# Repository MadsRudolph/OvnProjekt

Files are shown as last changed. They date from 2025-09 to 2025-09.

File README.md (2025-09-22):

# 🔥 Ovn-Projekt — Pure Analog & Digital Oven Controller (No MCU)






A fully hardware-based oven control system designed and built with **analog + digital electronics** only — **no microcontroller** or pre-programmed ICs.  
All schematics and PCBs were created in **KiCad**. The final project uses a **hierarchical schematic** so all subsystems connect cleanly in one place.

> This was a tough one: we built the oven before learning every theory detail in class. That made it frustrating at times — and incredibly satisfying when everything finally worked.

---

## 🚀 Quick Start (Open the Project)

1. Open **KiCad 7/8** (tested with 8).
2. Open the **main project**:
   - `./OVN/OVN.kicad_pro`
3. Open the **top schematic**:
   - `./OVN/OVN.kicad_sch`  
   This is the top-level design with a **hierarchical sheet** that pulls in all subsystems (analog control, digital timing/state machine, deviation display, oscillator).
4. Optional: open the **PCB**:
   - `./OVN/OVN.kicad_pcb`

> The subfolders contain **intermediate/local variants** and backups. They’re useful for history, but the **final connected design** lives in `OVN/`.

---

## 🎯 Project Goals

- Automatically cycle between **three set temperatures** (e.g., 50 °C → 110 °C → 80 °C → repeat)
- Hold each temperature for a **fixed duration** (e.g., ~80 s)
- Maintain temperature within **±1 °C** of the target
- Provide **safety shutdown** above a critical threshold (e.g., 130 °C)
- Show **real-time temperature deviation** on an LED bar
- Implement everything with **discrete analog + digital logic** (no MCU/firmware)

---

## 🧩 System Overview

The oven control system is composed of **four main subsystems**:

### 1) Digital Oscillator
Generates clock signals for counters/timers and ADC timing.
- RC network + digital logic
- Adjustable frequency outputs
- Example board size around *35 mm × 47 mm*

### 2) Deviation Display (Afvigelsesdisplay)
Real-time visualization of error between current temperature and setpoint.
- **ADC0804** A/D converter
- **Two 74HC238** decoders → **16 LEDs**
- Center LEDs ≈ in-range (green), outer LEDs ≈ negative/positive deviation

### 3) Analog Control Circuit
Compares measured temperature to selected setpoint and drives the heater.
- Sensor: **LM35**
- **Op-amps** for differential amplification & comparators for thresholds
- **CD4066** analog switch selects between three setpoints
- Provides a scaled signal for the deviation display

### 4) Digital State Machine & Timing
Sequences the temperature program and dwell times.
- **74HC163** counters + combinational logic
- Generates `T1/T2/T3` signals for setpoint selection
- Drives indicators (LEDs / 7-segment) and coordinates timing

---
<h2>🧾 Project Poster</h2>
<p align="center">
  <a href="./docs/Ovn_Projekt_Poster.pdf" target="_blank">
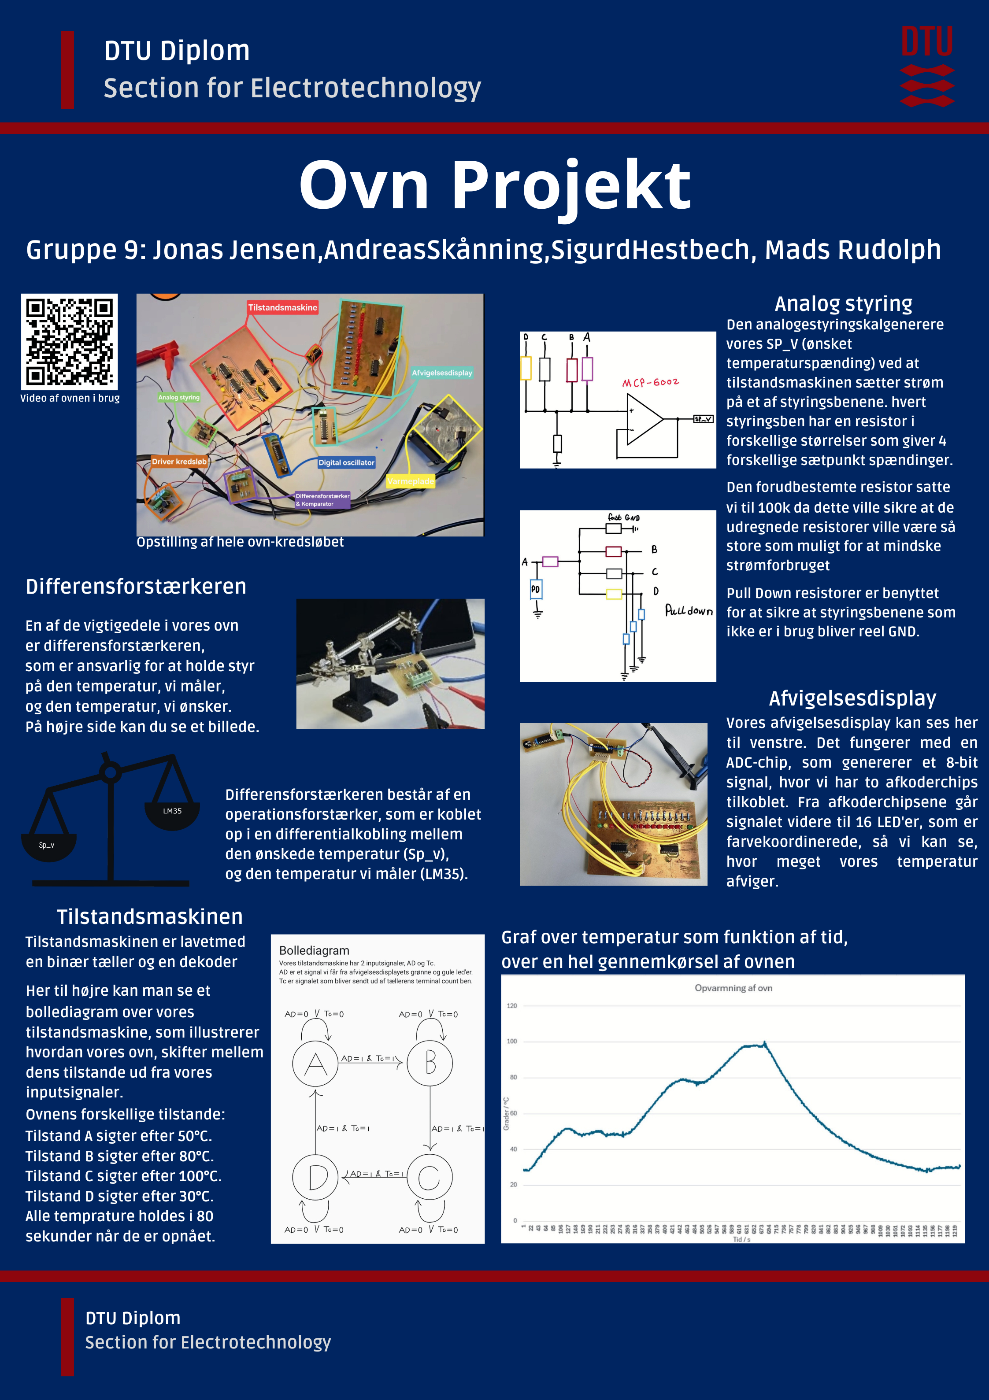
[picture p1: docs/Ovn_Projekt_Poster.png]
Oven Project Poster
    
  </a>
  <br>
  <em>Click to open the full PDF</em>
</p>
---
## 🛠 Tools & Key Components

- **Design:** KiCad (schematic + PCB)
- **Test Gear:** Multimeter, oscilloscope, logic probes/analyzers
- **Key ICs/Parts:** LM35, ADC0804, 74HC238, 74HC163, CD4066, MCP6002, passives, LEDs

---

## ⚡ Workflow

1. **Subsystem Breadboarding** → validate analog thresholds, timing, and LED decoding  
2. **KiCad Schematic & PCB** → create/clean symbols and **custom footprints** as needed  
3. **Integration** → hierarchical sheet in `OVN` ties everything together  
4. **Debug & Iterate** → scope timing edges, adjust thresholds, verify stability and safety

---

## 🌟 Key Learnings

- Designing robust control with **only analog/digital logic** (no firmware safety net)
- Practical timing, noise, and threshold trade-offs in real hardware
- **KiCad** hierarchical design, footprint creation, and multi-board bring-up
- System-level debugging with mixed-signal interactions

---

## 👥 Team

- **Mads Vølkers Rudolph**  
- **Jonas Beck Jensen**
- **Sigurd Hestbech**
- **Andreas Skaaning**

---

## 🚀 Future Improvements

- MCU-based mode for flexible profiles + logging (keeping the analog chain as backup)
- PID/PI control for even tighter regulation
- Small display (OLED/LCD) with progress and temperature graphs

---

## 🏁 Result

The integrated **OVN** project reflects the **final working oven**:  
- Automatic multi-temperature cycling with dwell times  
- Safety cutoff behavior verified  
- Deviation display and timing logic functioning reliably

**No MCU. Just electrons doing the choreography.**

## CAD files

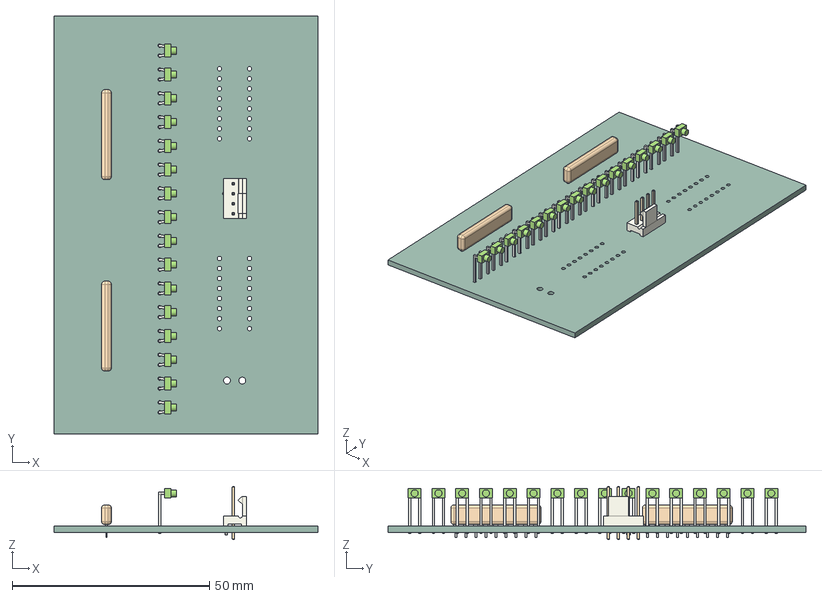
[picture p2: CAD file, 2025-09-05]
Afvigelsesdisplay/afvigelsesdisplay leds/leds/leds.step
67.0 x 106.0 x 13.5 mm
LED_D1.8mm_W1.8mm_H2.4mm_Horizontal_O1.27mm_Z8.2mm x 16
Fan_Pin_Header_Straight_1x04
R_Array_SIP9 x 2
leds_PCB

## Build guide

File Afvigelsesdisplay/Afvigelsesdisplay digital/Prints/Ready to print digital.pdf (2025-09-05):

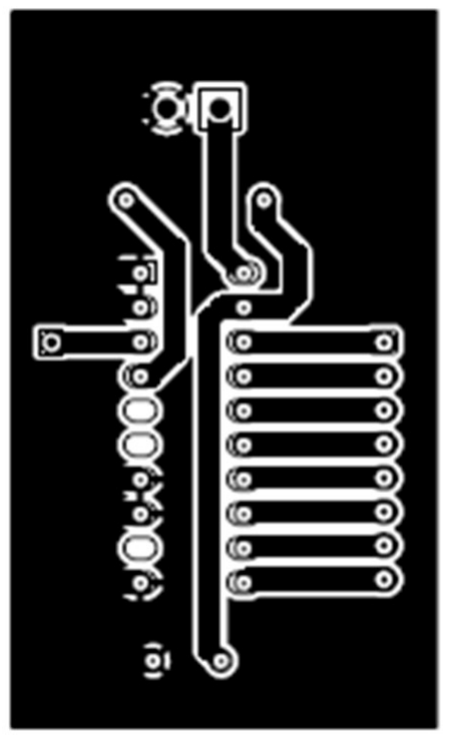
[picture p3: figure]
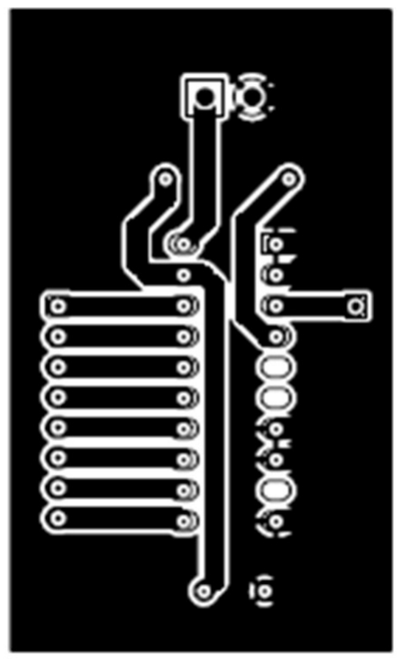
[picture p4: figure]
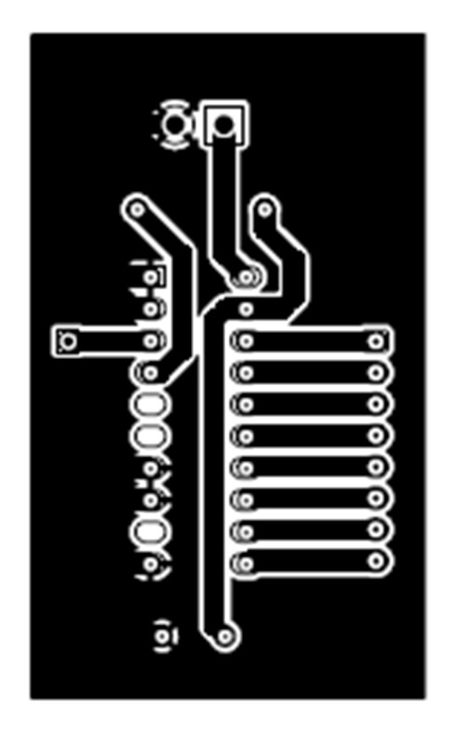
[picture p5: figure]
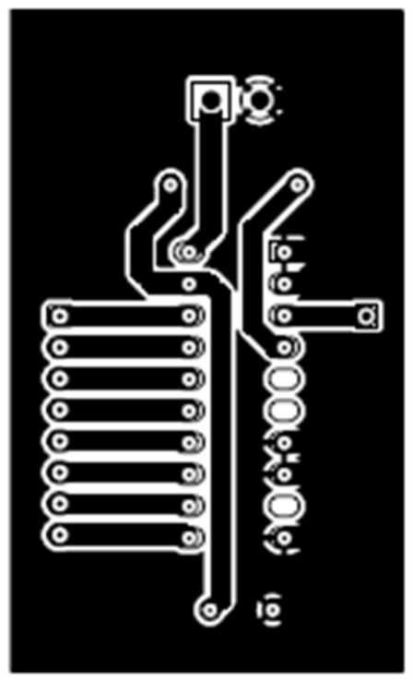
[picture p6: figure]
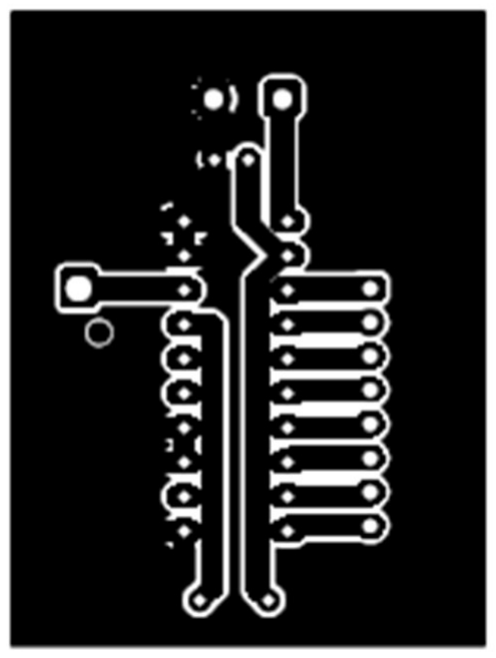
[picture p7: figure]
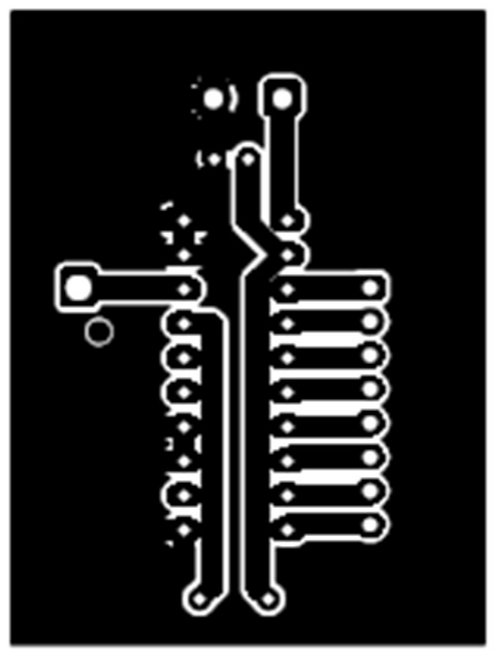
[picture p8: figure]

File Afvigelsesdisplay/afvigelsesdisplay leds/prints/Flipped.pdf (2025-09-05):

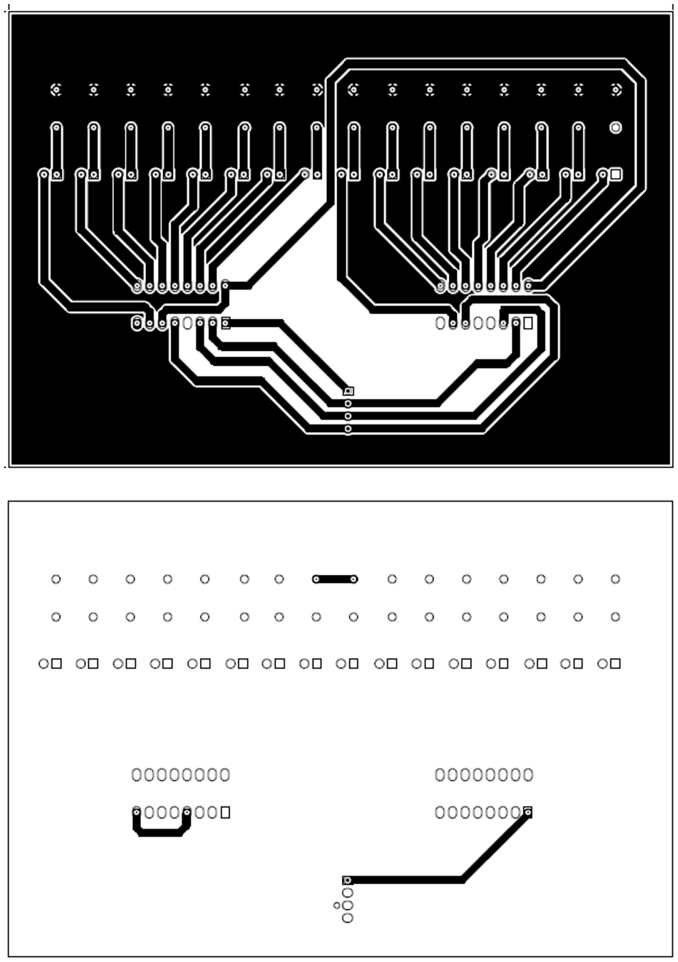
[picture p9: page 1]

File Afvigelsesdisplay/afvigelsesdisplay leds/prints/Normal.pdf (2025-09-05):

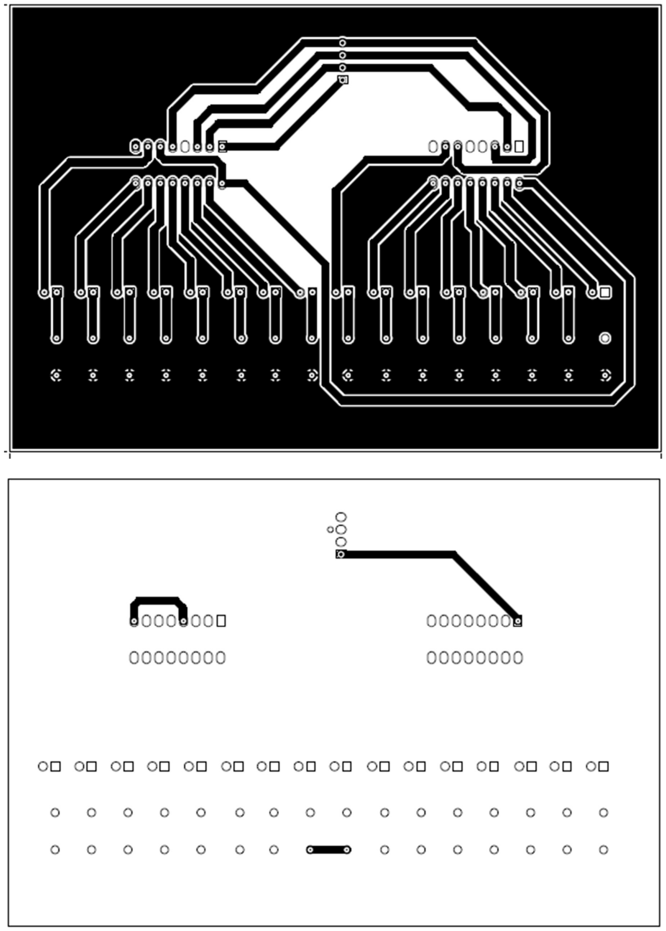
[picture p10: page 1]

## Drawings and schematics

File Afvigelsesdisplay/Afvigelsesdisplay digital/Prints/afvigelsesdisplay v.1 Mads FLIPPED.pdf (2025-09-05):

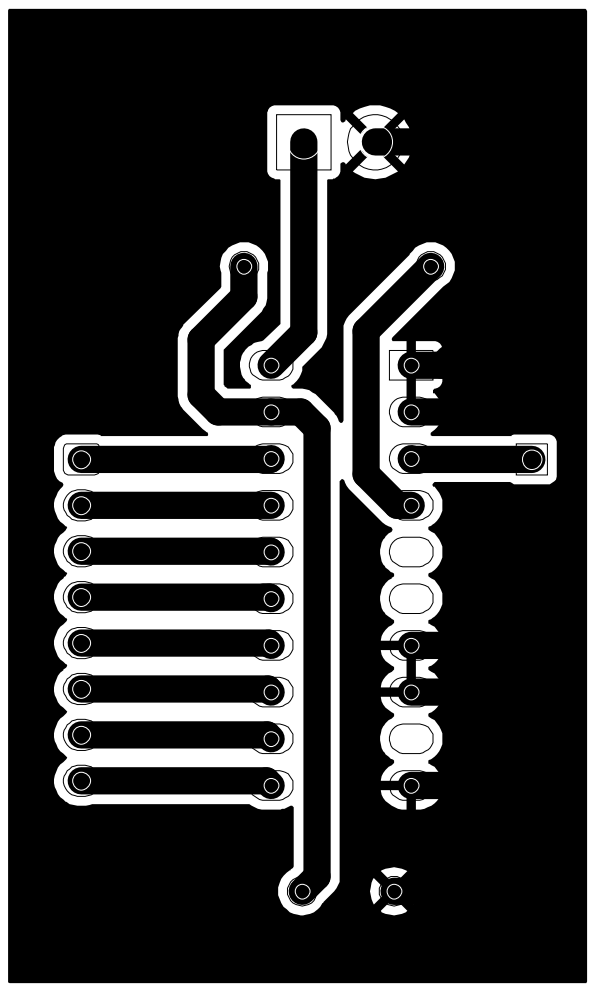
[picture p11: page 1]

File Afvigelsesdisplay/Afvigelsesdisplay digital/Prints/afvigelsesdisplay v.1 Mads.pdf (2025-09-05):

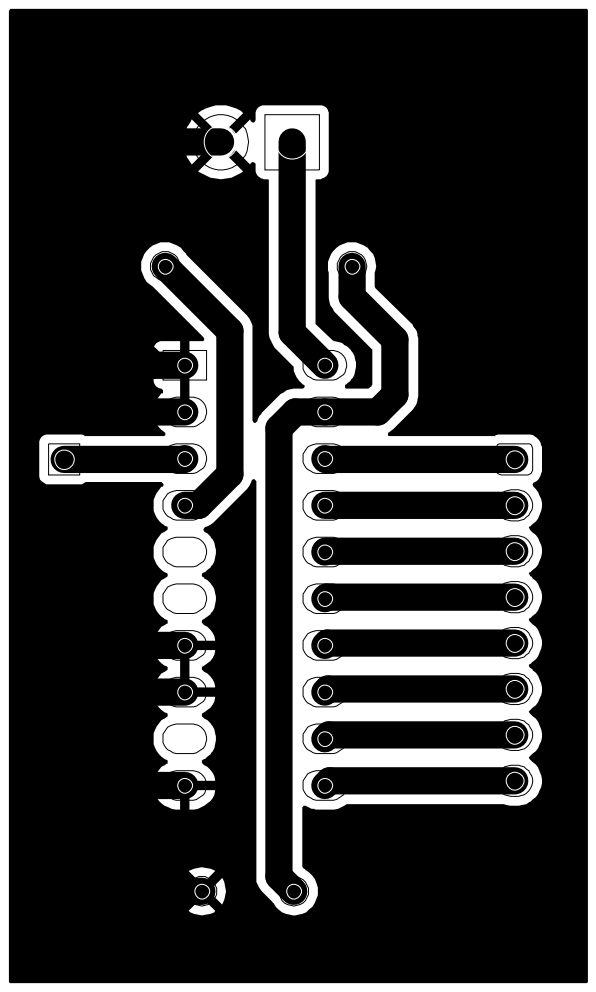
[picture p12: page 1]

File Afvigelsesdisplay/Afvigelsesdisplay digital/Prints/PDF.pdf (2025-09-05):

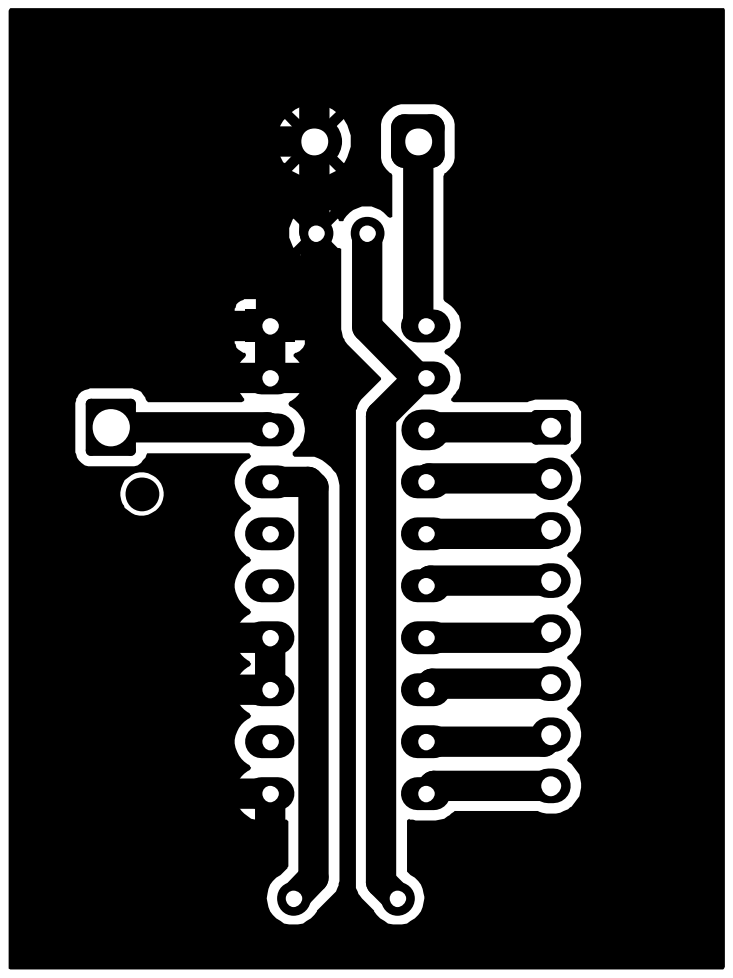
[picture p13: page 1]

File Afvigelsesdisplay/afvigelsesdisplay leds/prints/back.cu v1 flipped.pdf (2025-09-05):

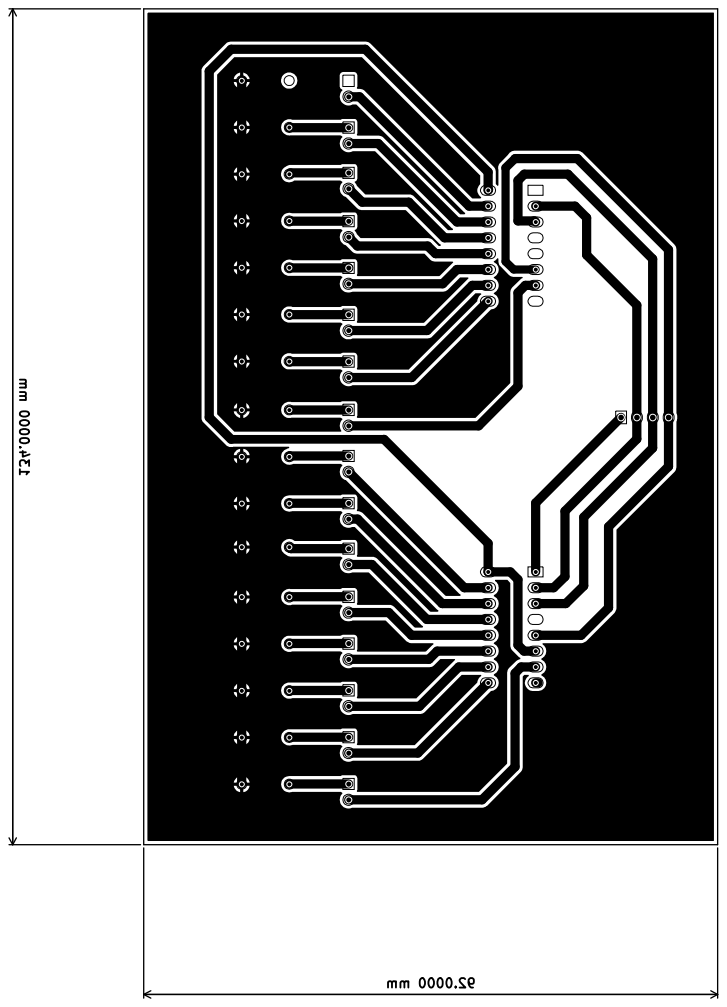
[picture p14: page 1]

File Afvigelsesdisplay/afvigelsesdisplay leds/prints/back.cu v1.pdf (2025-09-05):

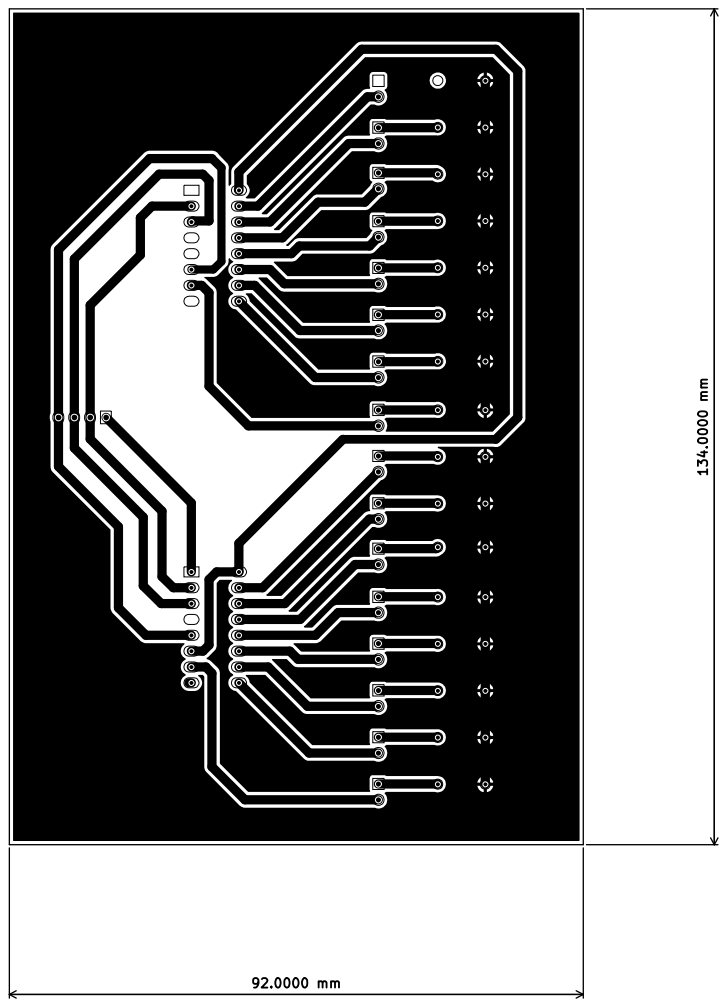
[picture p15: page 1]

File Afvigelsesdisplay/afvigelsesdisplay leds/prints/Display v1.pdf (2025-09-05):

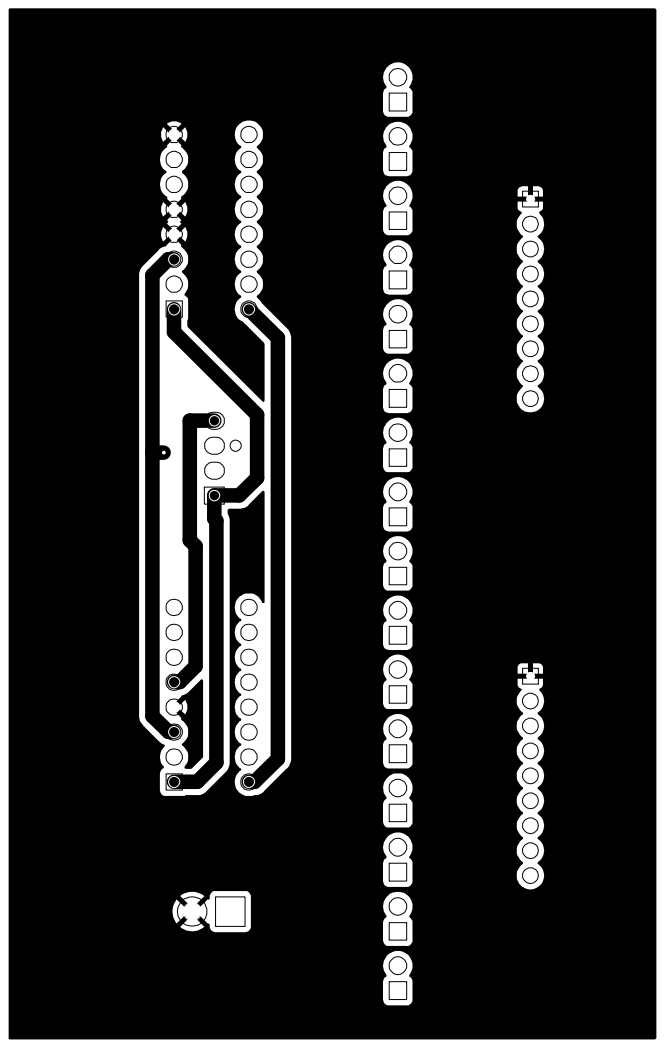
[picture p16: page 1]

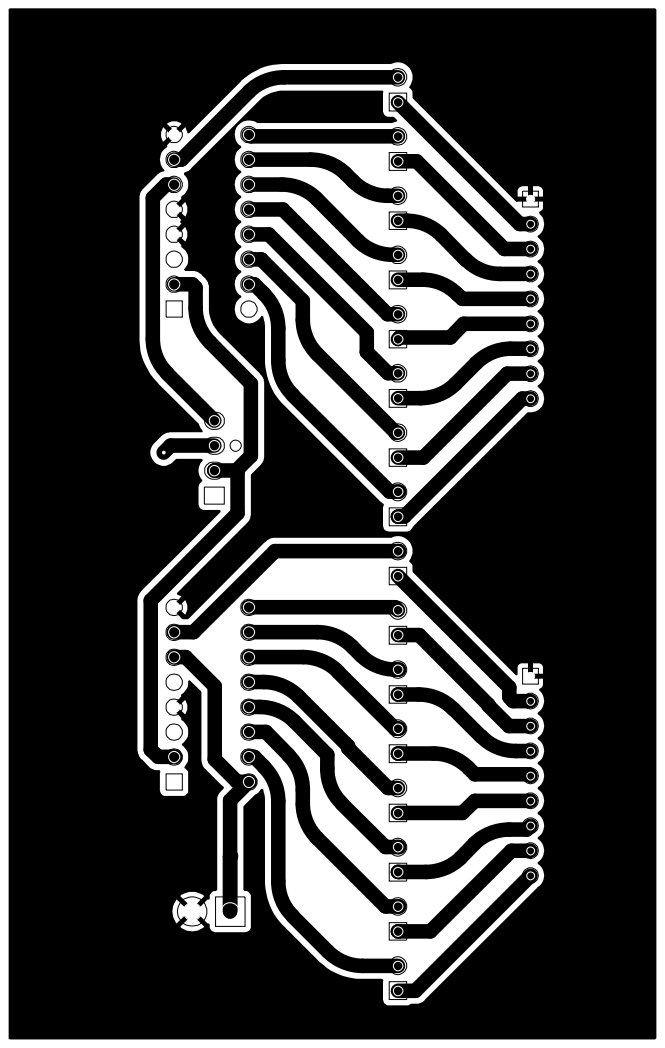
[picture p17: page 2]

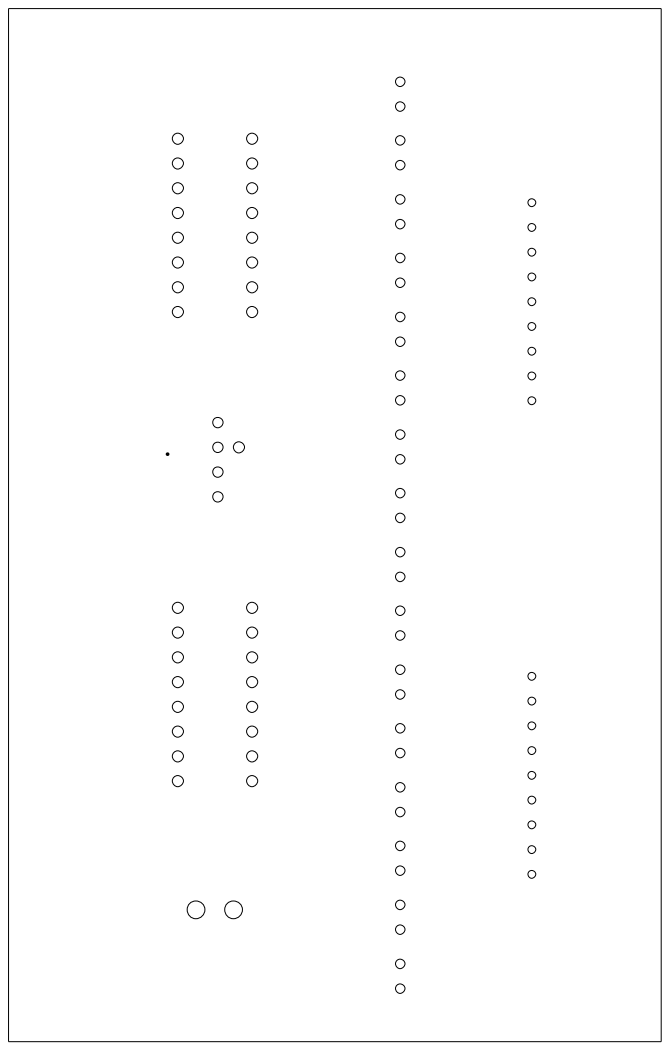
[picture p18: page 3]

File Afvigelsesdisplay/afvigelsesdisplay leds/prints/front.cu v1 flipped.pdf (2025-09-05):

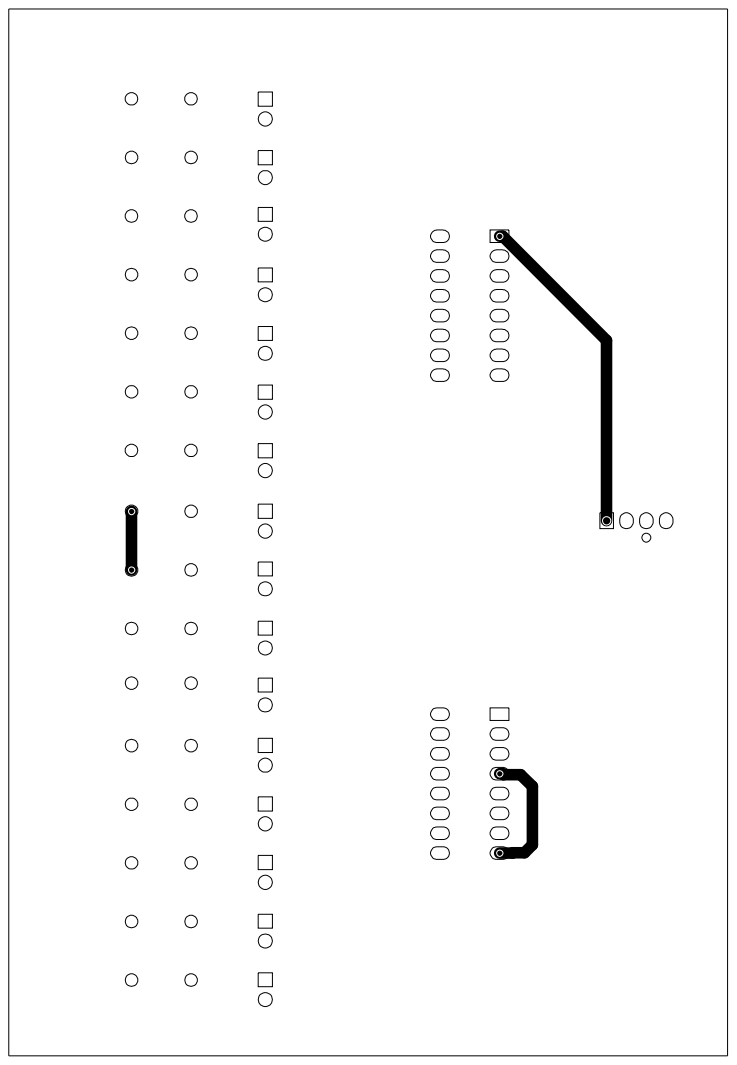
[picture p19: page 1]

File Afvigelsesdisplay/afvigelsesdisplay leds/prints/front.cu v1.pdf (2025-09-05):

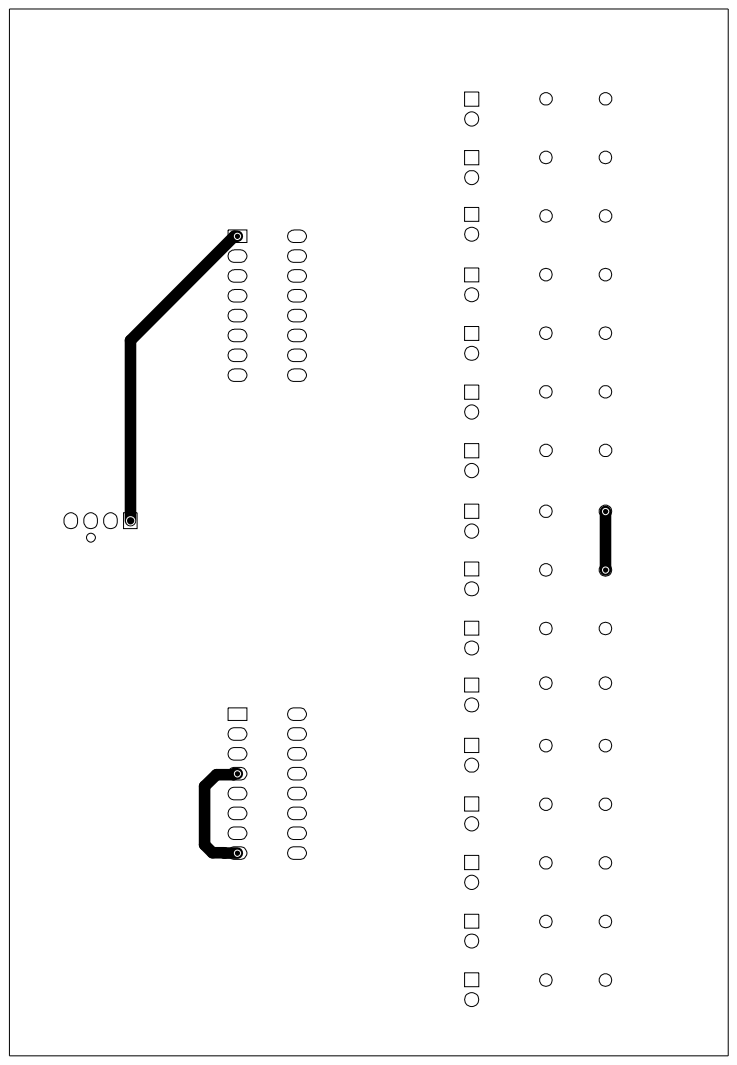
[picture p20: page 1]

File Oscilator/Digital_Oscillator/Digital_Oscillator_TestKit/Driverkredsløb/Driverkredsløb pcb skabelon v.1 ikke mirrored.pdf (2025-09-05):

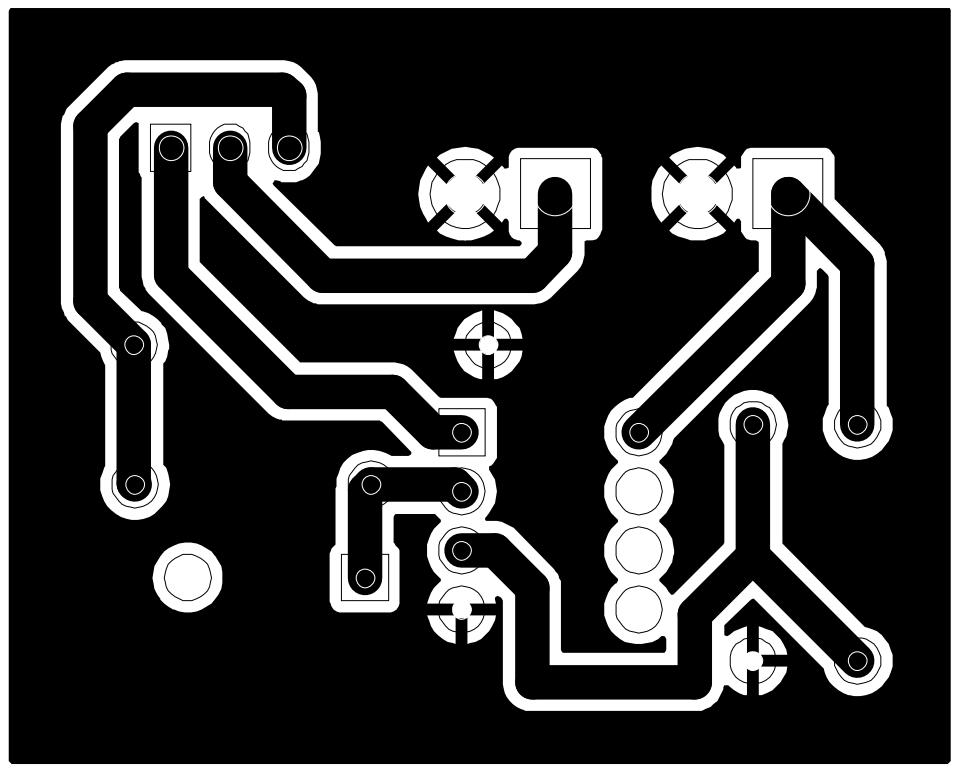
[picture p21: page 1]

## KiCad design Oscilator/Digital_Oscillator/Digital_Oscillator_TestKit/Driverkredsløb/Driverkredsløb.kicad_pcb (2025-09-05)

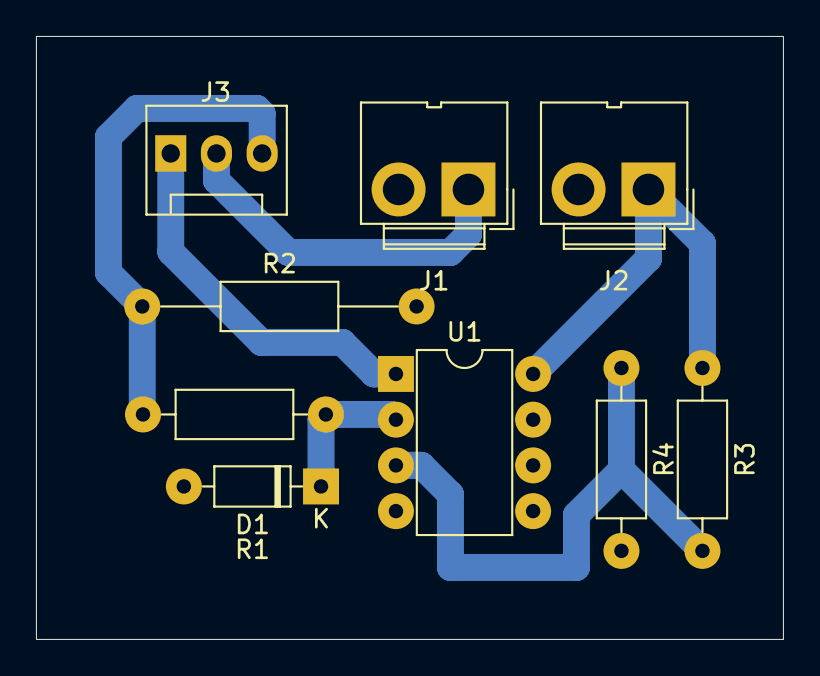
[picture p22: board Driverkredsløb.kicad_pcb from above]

Board: 2 copper layers, 41.5 x 33.5 mm, 9 parts (0 on the bottom side), 7 nets.

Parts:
D1: 1N4148; D_DO-35_SOD27_P7.62mm_Horizontal
J1, J2: Conn_01x02_Socket; JWT_A3963_1x02_P3.96mm_Vertical
J3: Conn_01x03_Socket; FanPinHeader_1x03_P2.54mm_Vertical
R1: 20k; R_Axial_DIN0207_L6.3mm_D2.5mm_P10.16mm_Horizontal
R2: 0.1; R_Axial_DIN0207_L6.3mm_D2.5mm_P15.24mm_Horizontal
R3: 15k; R_Axial_DIN0207_L6.3mm_D2.5mm_P10.16mm_Horizontal
R4: 300; R_Axial_DIN0207_L6.3mm_D2.5mm_P10.16mm_Horizontal
U1: MCP6002-xMC; DIP-8_W7.62mm

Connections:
GND: J1.2, J2.2, R2.2, R4.2, U1.4 (V-)
unnamed: D1.1 (K), R1.1, U1.2 (-)
unnamed: J1.1, J3.2
unnamed: J2.1, R3.1, U1.8 (V+)
unnamed: J3.1, U1.1
unnamed: J3.3, R1.2, R2.1
unnamed: R3.2, R4.1, U1.3 (+)

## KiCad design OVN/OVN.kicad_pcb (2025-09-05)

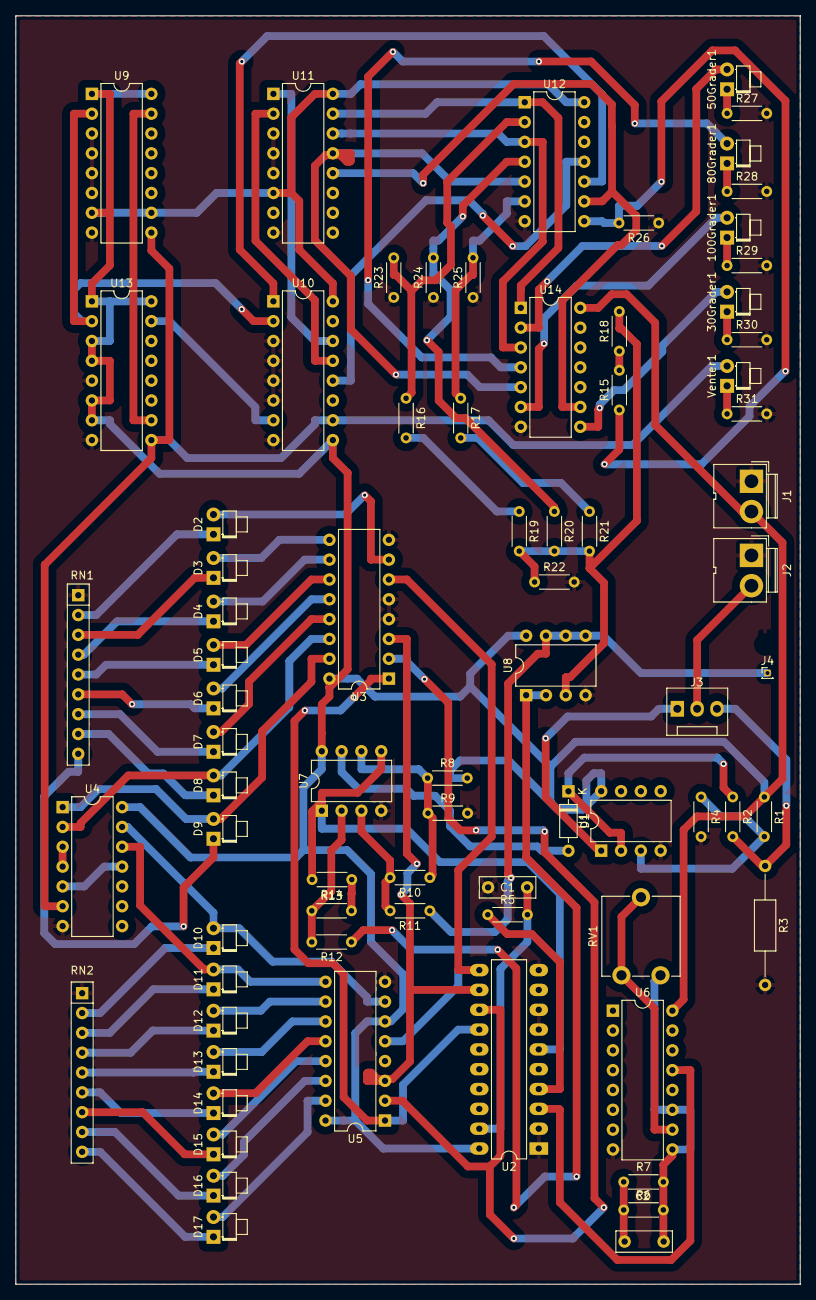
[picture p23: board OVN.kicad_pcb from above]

Board: 2 copper layers, 100.5 x 162.5 mm, 76 parts (0 on the bottom side), 87 nets.

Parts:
30Grader1, 50Grader1, 80Grader1, 100Grader1: LED; LED_D1.8mm_W1.8mm_H2.4mm_Horizontal_O1.27mm_Z8.2mm
C1: 150nF; C_Disc_D7.0mm_W2.5mm_P5.00mm
C2: 100 nF; C_Disc_D7.0mm_W2.5mm_P5.00mm
D1: 1N4148; D_DO-35_SOD27_P7.62mm_Horizontal
D2, D4, D5, D6, D7, D12, D13, D14, D15, D16, D17: R; LED_D1.8mm_W1.8mm_H2.4mm_Horizontal_O1.27mm_Z8.2mm
D3: LED; LED_D1.8mm_W1.8mm_H2.4mm_Horizontal_O1.27mm_Z8.2mm
D8, D11: GU; LED_D1.8mm_W1.8mm_H2.4mm_Horizontal_O1.27mm_Z8.2mm
D9, D10: GR; LED_D1.8mm_W1.8mm_H2.4mm_Horizontal_O1.27mm_Z8.2mm
J1, J2: Conn_01x02_Pin; JWT_A3963_1x02_P3.96mm_Vertical
J3: Conn_01x03_Socket; FanPinHeader_1x03_P2.54mm_Vertical
J4: LM35; PinHeader_1x01_P1.00mm_Vertical
R1: 15k; R_Axial_DIN0204_L3.6mm_D1.6mm_P5.08mm_Horizontal
R2: 20k; R_Axial_DIN0204_L3.6mm_D1.6mm_P5.08mm_Horizontal
R3: 0.1; R_Axial_DIN0207_L6.3mm_D2.5mm_P15.24mm_Horizontal
R4: 300; R_Axial_DIN0204_L3.6mm_D1.6mm_P5.08mm_Horizontal
R5, R22: 100K; R_Axial_DIN0204_L3.6mm_D1.6mm_P5.08mm_Horizontal
R6: 4.3k; R_Axial_DIN0204_L3.6mm_D1.6mm_P5.08mm_Horizontal
R7: 123K6; R_Axial_DIN0204_L3.6mm_D1.6mm_P5.08mm_Horizontal
R8, R9, R14: 11.5K; R_Axial_DIN0204_L3.6mm_D1.6mm_P5.08mm_Horizontal
R10, R13: 301K; R_Axial_DIN0204_L3.6mm_D1.6mm_P5.08mm_Horizontal
R11, R12: 10K; R_Axial_DIN0204_L3.6mm_D1.6mm_P5.08mm_Horizontal
R15: 787K; R_Axial_DIN0204_L3.6mm_D1.6mm_P5.08mm_Horizontal
R16: 5.6K; R_Axial_DIN0204_L3.6mm_D1.6mm_P5.08mm_Horizontal
R17: 237K; R_Axial_DIN0204_L3.6mm_D1.6mm_P5.08mm_Horizontal
R18: 15K; R_Axial_DIN0204_L3.6mm_D1.6mm_P5.08mm_Horizontal
R19: 475K; R_Axial_DIN0204_L3.6mm_D1.6mm_P5.08mm_Horizontal
R20: 300K; R_Axial_DIN0204_L3.6mm_D1.6mm_P5.08mm_Horizontal
R21: 2.6K; R_Axial_DIN0204_L3.6mm_D1.6mm_P5.08mm_Horizontal
R23, R24, R25, R26, R27, R28, R29, R30, R31: R; R_Axial_DIN0204_L3.6mm_D1.6mm_P5.08mm_Horizontal
RN1, RN2: R_Network08; R_Array_SIP9
RV1: R_Potentiometer_Small; Potentiometer_ACP_CA9-V10_Vertical
U1, U7, U8: MCP6002-xMC; DIP-8_W7.62mm
U2: ADC0804LCN; DIP-20_W7.62mm_LongPads
U3, U5: 74HC238N; DIP-16_W7.62mm
U4: SN74HC86; DIP-14_W7.62mm
U6: 74HC4060; DIP-16_W7.62mm
U9, U10, U13: SN74HC163N; DIP-16_W7.62mm
U11: 74HC138N; DIP-16_W7.62mm
U12, U14: SN74HC04N; DIP-14_W7.62mm
Venter1: LED; LED_D1.8mm_W1.8mm_H2.4mm_Horizontal_O1.27mm_Z8.2mm

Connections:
10V-30V: J2.2, J3.2
+5V: J1.2, R1.1, R8.2, U1.8 (V+), U2.20 (VCC), U3.16 (VCC), U4.14 (VCC), U5.6 (E3), U5.16 (VCC), U6.16 (VDD), U7.8 (V+), U8.8 (V+), U9.1 (~MR), U9.7 (CEP), U9.10 (CET), U9.16 (VCC), U10.9 (~LOAD), U10.16 (VCC), U11.6 (E3), U11.16 (VCC), U12.14 (VCC), U13.1 (~MR), U13.3 (D0), U13.4 (D1), U13.6 (D3), U13.7 (CEP), U13.16 (VCC), U14.14 (VCC)
/ADC Convertor/DB4: U2.14 (DB4), U3.1 (A0), U5.1 (A0)
/ADC Convertor/DB5: U2.13 (DB5), U3.2 (A1), U5.2 (A1)
/ADC Convertor/DB6: U2.12 (DB6), U3.3 (A2), U5.3 (A2)
/ADC Convertor/DB7: U2.11 (DB7), U3.6 (E3), U5.5 (~E2)
/ADC Convertor/WR_in: U2.3 (~WR), U6.13 (Q9), U9.2 (CLK), U10.2 (CLK), U13.2 (CLK)
/Afvigelsesdisplay/Steady state: U4.6 (3Y), U9.9 (~LOAD), U10.10 (CET), U13.9 (~LOAD), Venter1.2 (A)
/Analog styring Differensforstærker/V-Ovn: D1.2 (A), U7.7
/Analog styring spændingsdeler/30°C: R15.1, R26.2, U12.8 (4Y)
/Analog styring spændingsdeler/50°C: R16.1, R23.2, U12.2 (1Y)
/Analog styring spændingsdeler/80°C: R20.1, R24.2, U12.4 (2Y)
/Analog styring spændingsdeler/100°C: R17.1, R25.2, U12.6 (3Y)
Afv_displ_adc: R14.2, U2.6 (VIN(+)), U7.1, U7.5 (+)
GND: C1.1, J1.1, J2.1, R3.2, R4.2, R9.2, R22.2, R23.1, R24.1, R25.1, R26.1, R27.2, R28.2, R29.2, R30.2, R31.2, RN1.1 (common), RN2.1 (common), U1.4 (V-), U2.1 (~CS), U2.2 (~RD), U2.7 (VIN(-)), U2.8 (AGND), U2.10 (DGND), U3.4 (~E1), U3.5 (~E2), U3.8 (GND), U4.7 (GND), U5.4 (~E1), U5.8 (GND), U6.8 (VSS), U6.12 (CLR), U7.4 (V-), U8.4 (V-), U9.3 (D0), U9.4 (D1), U9.5 (D2), U9.6 (D3), U9.8 (GND), U10.3 (D0), U10.4 (D1), U10.5 (D2), U10.6 (D3), U10.8 (GND), U11.3 (A2), U11.4 (~E1), U11.5 (~E2), U11.8 (GND), U12.7 (GND), U13.5 (D2), U13.8 (GND), U14.7 (GND)
LM35_out: J4.1, R11.1, U8.5 (+), U8.6 (-), U8.7
unnamed: 30Grader1.2 (A), U14.8 (4Y)
unnamed: 30Grader1.1 (K), R30.1
unnamed: 50Grader1.2 (A), U14.2 (1Y)
unnamed: 50Grader1.1 (K), R27.1
unnamed: 80Grader1.2 (A), U14.4 (2Y)
unnamed: 80Grader1.1 (K), R28.1
unnamed: 100Grader1.2 (A), U14.6 (3Y)
unnamed: 100Grader1.1 (K), R29.1
unnamed: C2.1, R6.1, R7.1
unnamed: D1.1 (K), R2.1, U1.2 (-)
unnamed: D2.2 (A), U3.7 (Y7)
unnamed: D2.1 (K), RN1.2 (R1)
unnamed: D3.2 (A), U3.9 (Y6)
unnamed: D3.1 (K), RN1.3 (R2)
unnamed: D4.2 (A), U3.10 (Y5)
unnamed: D4.1 (K), RN1.4 (R3)
unnamed: D5.2 (A), U3.11 (Y4)
unnamed: D5.1 (K), RN1.5 (R4)
unnamed: D6.2 (A), U3.12 (Y3)
unnamed: D6.1 (K), RN1.6 (R5)
unnamed: D7.2 (A), U3.13 (Y2)
unnamed: D7.1 (K), RN1.7 (R6)
unnamed: D8.2 (A), U3.14 (Y1), U4.2 (1Y)
unnamed: D8.1 (K), RN1.8 (R7)
unnamed: D9.2 (A), U3.15 (Y0), U4.1 (1A)
unnamed: D9.1 (K), RN1.9 (R8)
unnamed: D10.2 (A), U4.13 (6A), U5.7 (Y7)
unnamed: D10.1 (K), RN2.2 (R1)
unnamed: D11.2 (A), U4.12 (6Y), U5.9 (Y6)
unnamed: D11.1 (K), RN2.3 (R2)
unnamed: D12.2 (A), U5.10 (Y5)
unnamed: D12.1 (K), RN2.4 (R3)
unnamed: D13.2 (A), U5.11 (Y4)
unnamed: D13.1 (K), RN2.5 (R4)
unnamed: D14.2 (A), U5.12 (Y3)
unnamed: D14.1 (K), RN2.6 (R5)
unnamed: D15.2 (A), U5.13 (Y2)
unnamed: D15.1 (K), RN2.7 (R6)
unnamed: D16.2 (A), U5.14 (Y1)
unnamed: D16.1 (K), RN2.8 (R7)
unnamed: D17.2 (A), U5.15 (Y0)
unnamed: D17.1 (K), RN2.9 (R8)
unnamed: J3.1, U1.1
unnamed: J3.3, R2.2, R3.1
unnamed: R13.2, R14.1
unnamed: R15.2, R18.1
unnamed: R16.2, R19.1
unnamed: R17.2, R21.1
unnamed: R1.2, R4.1, U1.3 (+)
unnamed: R5.1, U2.4 (CLK_IN)
unnamed: C1.2, R5.2, U2.19 (CLK_R)
unnamed: U4.3 (2A), U4.4 (2Y)
unnamed: U4.5 (3A), U4.11 (5A)
unnamed: C2.2, R6.2, R7.2, RV1.1, U6.9 (~Φ0), U6.11 (~Φ1)
unnamed: RV1.2, RV1.3, U6.10 (Φ0)
unnamed: R10.2, R11.2, U7.3 (+)
unnamed: R12.2, R13.1, U7.2 (-)
unnamed: R8.1, R9.1, R10.1, U7.6 (-)
unnamed: R18.2, R19.2, R20.2, R21.2, R22.1, U8.3 (+)
unnamed: U10.7 (CEP), U13.15 (TC)
unnamed: U10.14 (Q0), U11.1 (A0)
unnamed: U10.13 (Q1), U11.2 (A1)
unnamed: U10.12 (Q2), U12.11 (5A)
unnamed: U10.1 (~MR), U12.10 (5Y)
unnamed: U11.15 (Y0), U12.1 (1A), U14.1 (1A)
unnamed: U11.14 (Y1), U12.3 (2A), U14.3 (2A)
unnamed: U11.13 (Y2), U12.5 (3A), U14.5 (3A)
unnamed: U11.12 (Y3), U12.9 (4A), U14.9 (4A)
unnamed: U9.15 (TC), U13.10 (CET)
unnamed: R31.1, Venter1.1 (K)
Sp_v: R12.1, U8.1, U8.2 (-)

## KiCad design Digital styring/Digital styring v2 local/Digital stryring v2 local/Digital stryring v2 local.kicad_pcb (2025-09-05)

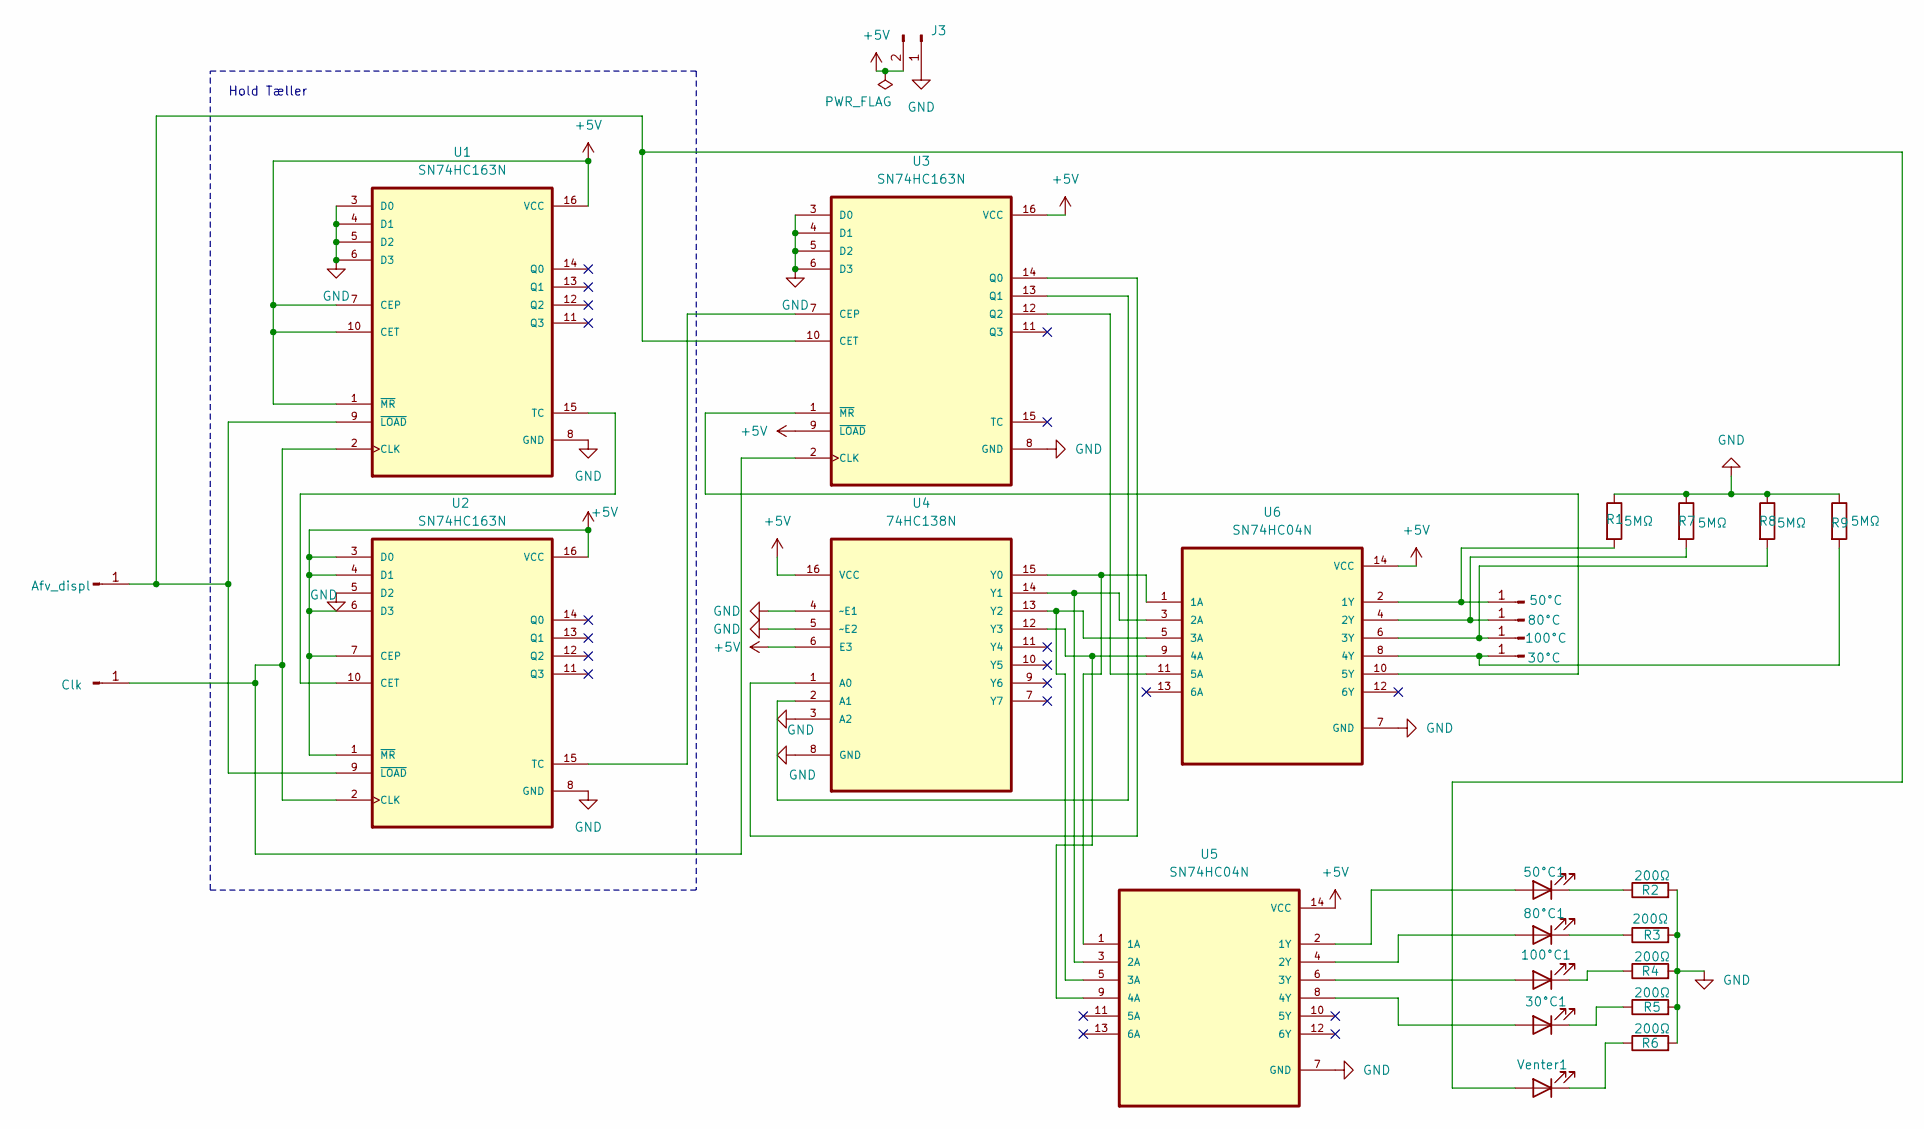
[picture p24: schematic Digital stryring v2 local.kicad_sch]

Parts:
30°C1, 50°C1, 80°C1, 100°C1: LED; LED_D1.8mm_W1.8mm_H2.4mm_Horizontal_O1.27mm_Z8.2mm
J1: Afv_displ; PinHeader_1x01_P1.00mm_Vertical
J2: Clk; PinHeader_1x01_P1.00mm_Vertical
J3: Conn_01x02_Pin; JWT_A3963_1x02_P3.96mm_Vertical
J4: 50°C; PinHeader_1x01_P1.00mm_Vertical
J5: 80°C; PinHeader_1x01_P1.00mm_Vertical
J6: 100°C; PinHeader_1x01_P1.00mm_Vertical
J7: 30°C; PinHeader_1x01_P1.00mm_Vertical
R1, R7, R8, R9: 5MΩ; R_Axial_DIN0204_L3.6mm_D1.6mm_P7.62mm_Horizontal
R2, R3, R4, R5, R6: 200Ω; R_Axial_DIN0204_L3.6mm_D1.6mm_P5.08mm_Horizontal
U1, U2, U3: SN74HC163N; DIP-16_W7.62mm
U4: 74HC138N; DIP-16_W7.62mm; MPN 74HC238N
U5, U6: SN74HC04N; DIP-14_W7.62mm
Venter1: LED; LED_D1.8mm_W1.8mm_H2.4mm_Horizontal_O1.27mm_Z8.2mm

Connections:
+5V: J3.2, U1.1 (~MR), U1.7 (CEP), U1.10 (CET), U1.16 (VCC), U2.1 (~MR), U2.3 (D0), U2.4 (D1), U2.6 (D3), U2.7 (CEP), U2.16 (VCC), U3.9 (~LOAD), U3.16 (VCC), U4.6 (E3), U4.16 (VCC), U5.14 (VCC), U6.14 (VCC)
GND: J3.1, R1.1, R2.2, R3.2, R4.2, R5.2, R6.2, R7.1, R8.1, R9.1, U1.3 (D0), U1.4 (D1), U1.5 (D2), U1.6 (D3), U1.8 (GND), U2.5 (D2), U2.8 (GND), U3.3 (D0), U3.4 (D1), U3.5 (D2), U3.6 (D3), U3.8 (GND), U4.3 (A2), U4.4 (~E1), U4.5 (~E2), U4.8 (GND), U5.7 (GND), U6.7 (GND)
unnamed: 30°C1.2 (A), U5.8 (4Y)
unnamed: 30°C1.1 (K), R5.1
unnamed: 50°C1.2 (A), U5.2 (1Y)
unnamed: 50°C1.1 (K), R2.1
unnamed: 80°C1.2 (A), U5.4 (2Y)
unnamed: 80°C1.1 (K), R3.1
unnamed: 100°C1.2 (A), U5.6 (3Y)
unnamed: 100°C1.1 (K), R4.1
unnamed: J1.1, U1.9 (~LOAD), U2.9 (~LOAD), U3.10 (CET), Venter1.2 (A)
unnamed: J2.1, U1.2 (CLK), U2.2 (CLK), U3.2 (CLK)
unnamed: J4.1, R1.2, U6.2 (1Y)
unnamed: J5.1, R7.2, U6.4 (2Y)
unnamed: J6.1, R8.2, U6.6 (3Y)
unnamed: J7.1, R9.2, U6.8 (4Y)
unnamed: U1.15 (TC), U2.10 (CET)
unnamed: U2.15 (TC), U3.7 (CEP)
unnamed: U3.14 (Q0), U4.1 (A0)
unnamed: U3.13 (Q1), U4.2 (A1)
unnamed: U3.12 (Q2), U6.11 (5A)
unnamed: U3.1 (~MR), U6.10 (5Y)
unnamed: U4.15 (Y0), U5.1 (1A), U6.1 (1A)
unnamed: U4.14 (Y1), U5.3 (2A), U6.3 (2A)
unnamed: U4.13 (Y2), U5.5 (3A), U6.5 (3A)
unnamed: U4.12 (Y3), U5.9 (4A), U6.9 (4A)
unnamed: R6.1, Venter1.1 (K)

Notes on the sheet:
Hold Tæller

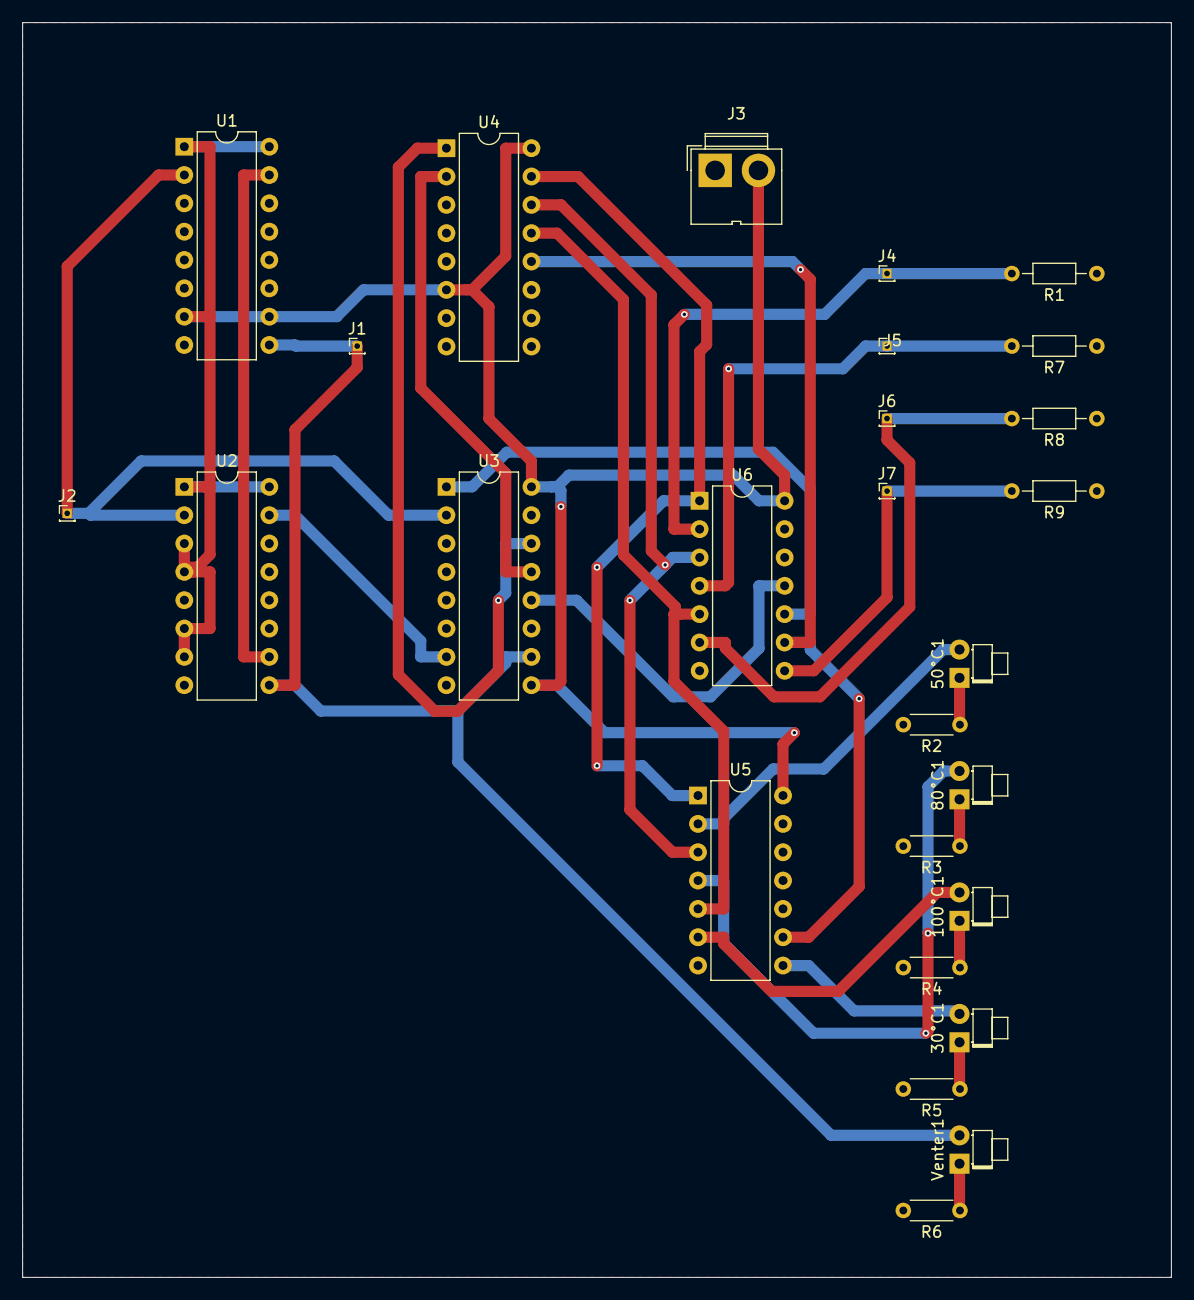
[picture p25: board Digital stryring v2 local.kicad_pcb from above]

Board: 2 copper layers, 103.0 x 112.5 mm, 27 parts (0 on the bottom side), 27 nets.

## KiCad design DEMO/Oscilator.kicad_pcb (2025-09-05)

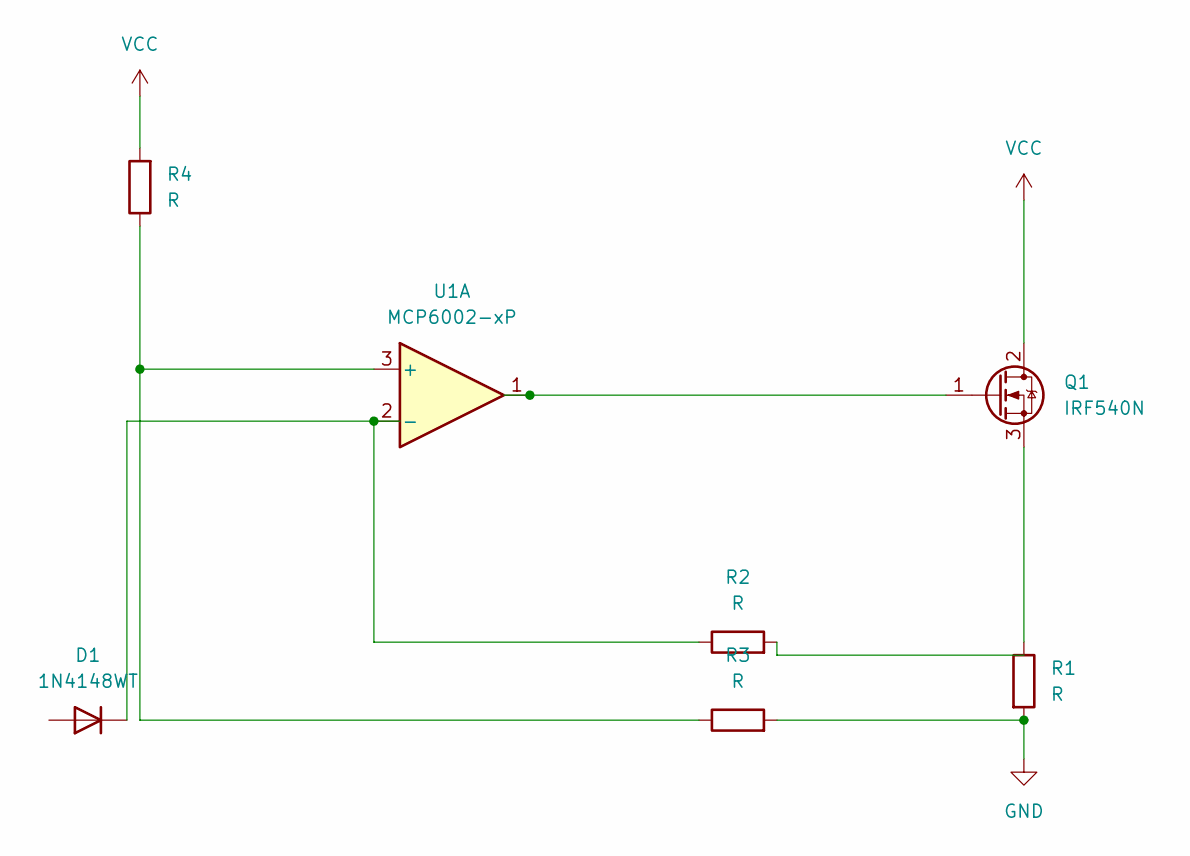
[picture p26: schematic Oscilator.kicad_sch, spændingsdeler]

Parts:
D1: 1N4148WT; D_SOD-523
Q1: IRF540N; TO-220-3_Vertical
R1, R2, R3, R4: R; R_Axial_DIN0207_L6.3mm_D2.5mm_P7.62mm_Horizontal
U1: MCP6002-xP; CERDIP-8_W7.62mm_SideBrazed_Socket

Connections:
GND: R1.2, R3.2
unnamed: D1.1 (K), R2.1, U1.2 (-)
unnamed: Q1.1 (G), U1.1
unnamed: Q1.3 (S), R1.1
unnamed: R3.1, R4.1, U1.3 (+)
VCC: Q1.2 (D), R4.2

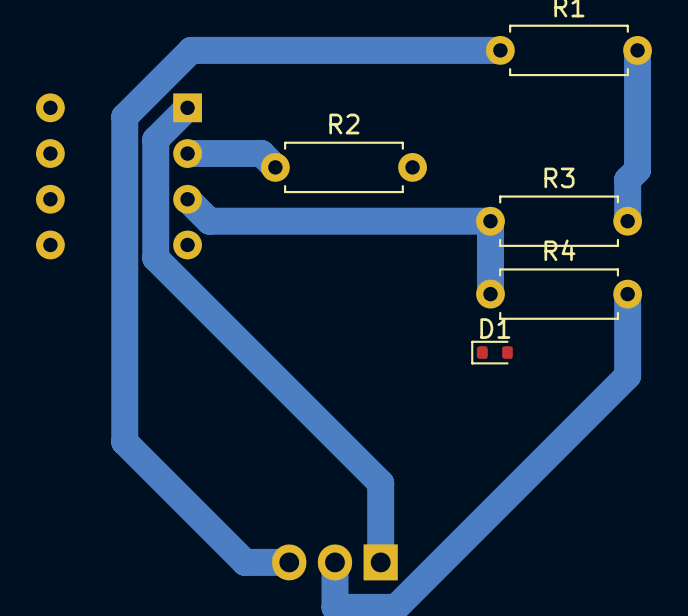
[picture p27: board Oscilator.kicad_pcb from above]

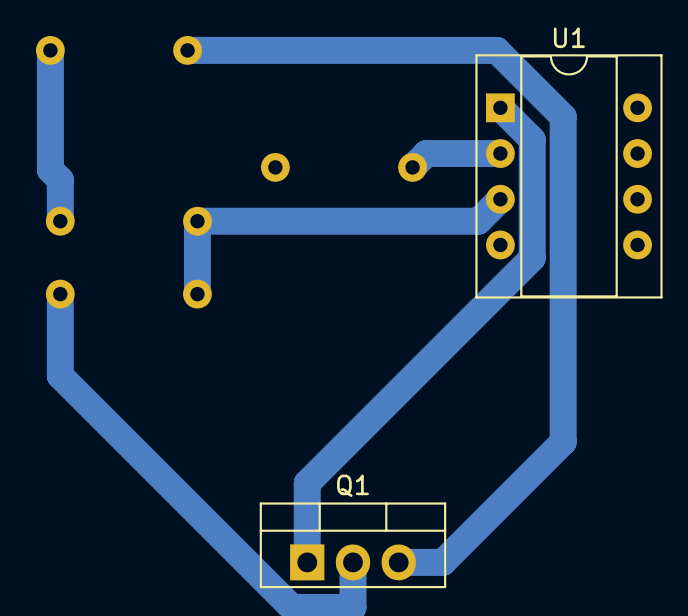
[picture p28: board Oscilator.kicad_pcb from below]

Board: 2 copper layers, 7 parts (2 on the bottom side), 6 nets.

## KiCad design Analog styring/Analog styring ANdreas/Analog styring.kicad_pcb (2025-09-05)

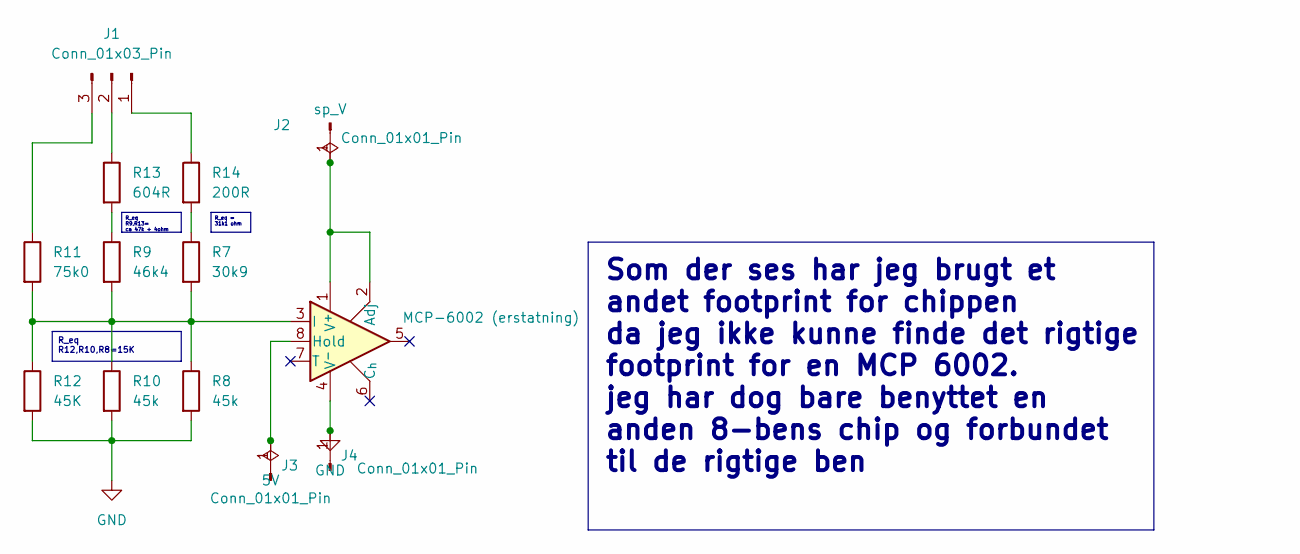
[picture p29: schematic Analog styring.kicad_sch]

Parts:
J1: Conn_01x03_Pin; FanPinHeader_1x03_P2.54mm_Vertical
J2, J3, J4: Conn_01x01_Pin; PinHeader_1x01_P1.00mm_Vertical
R7: 30k9; R_Axial_DIN0204_L3.6mm_D1.6mm_P2.54mm_Vertical
R8, R10: 45k; R_Axial_DIN0204_L3.6mm_D1.6mm_P2.54mm_Vertical
R9: 46k4; R_Axial_DIN0204_L3.6mm_D1.6mm_P2.54mm_Vertical
R11: 75k0; R_Axial_DIN0204_L3.6mm_D1.6mm_P2.54mm_Vertical
R12: 45K; R_Axial_DIN0204_L3.6mm_D1.6mm_P2.54mm_Vertical
R13: 604R; R_Axial_DIN0204_L3.6mm_D1.6mm_P2.54mm_Vertical
R14: 200R; R_Axial_DIN0204_L3.6mm_D1.6mm_P2.54mm_Vertical
U1: MCP-6002 (erstatning); DIP-8_W7.62mm

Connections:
GND: J4.1, R8.2, R10.2, R12.2, U1.4 (V^{-})
unnamed: J1.1, R14.1
unnamed: J1.2, R13.1
unnamed: J1.3, R11.1
unnamed: J2.1, U1.1 (V^{+}), U1.2 (Adj)
unnamed: J3.1, U1.8 (Hold)
unnamed: R9.1, R13.2
unnamed: R7.1, R14.2
unnamed: R7.2, R8.1, R9.2, R10.1, R11.2, R12.1, U1.3 (I)

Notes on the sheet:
Som der ses har jeg brugt et andet footprint for chippen da jeg ikke kunne finde det rigtige footprint for en MCP 6002. jeg har dog bare benyttet en anden 8-bens chip og forbundet til de rigtige ben
R_eq R9,R13= ca 47k + 4ohm
R_eq R12,R10,R8=15K
R_eq = 31k1 ohm

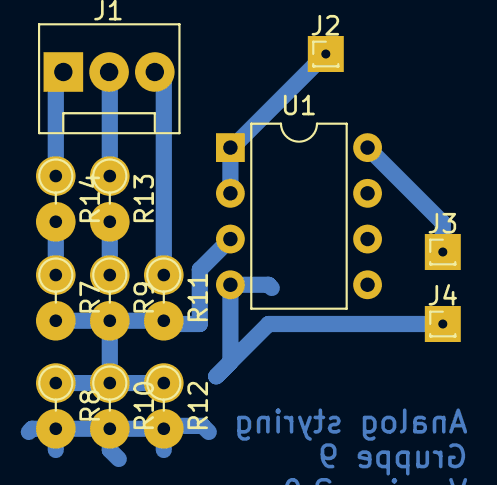
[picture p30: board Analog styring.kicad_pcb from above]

Board: 2 copper layers, 13 parts (0 on the bottom side), 9 nets.

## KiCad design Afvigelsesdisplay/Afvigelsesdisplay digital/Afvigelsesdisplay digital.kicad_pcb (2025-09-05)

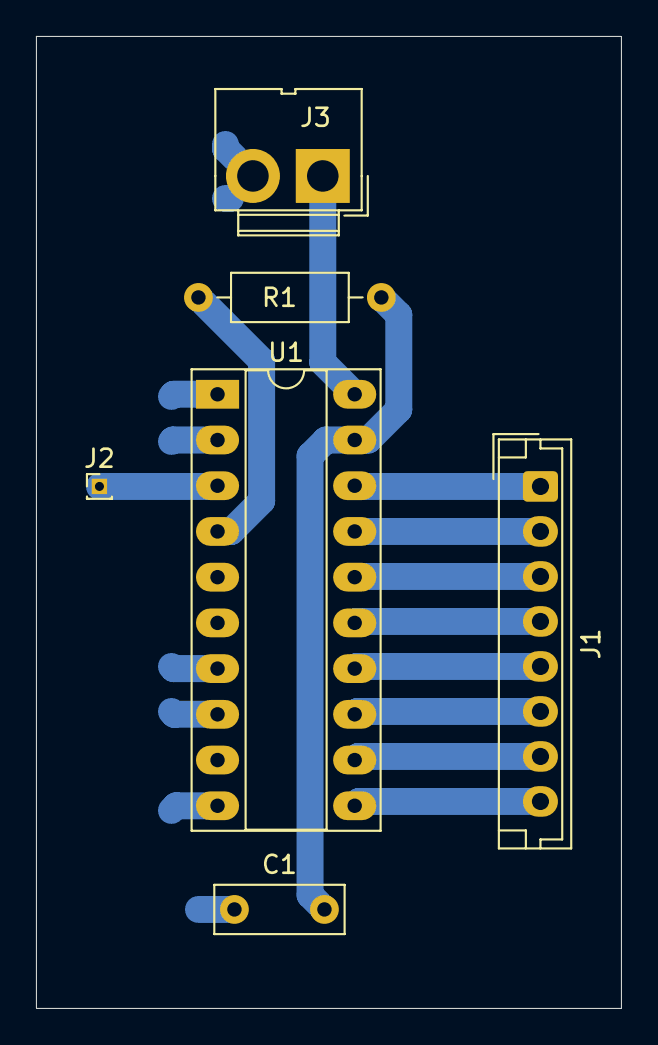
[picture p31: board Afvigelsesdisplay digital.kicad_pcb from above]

Board: 2 copper layers, 32.5 x 54.0 mm, 6 parts (0 on the bottom side), 13 nets.

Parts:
C1: 150nF; C_Disc_D7.0mm_W2.5mm_P5.00mm
J1: Conn_01x08_Socket; JST_EH_B8B-EH-A_1x08_P2.50mm_Vertical
J2: Conn_01x01_Pin; PinHeader_1x01_P1.00mm_Vertical
J3: Conn_01x02_Pin; JWT_A3963_1x02_P3.96mm_Vertical
R1: 100K; R_Axial_DIN0207_L6.3mm_D2.5mm_P10.16mm_Horizontal
U1: ADC0804LCN; CERDIP-20_W7.62mm_SideBrazed_LongPads_Socket

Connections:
GND: C1.1, J3.2, U1.1 (~CS), U1.2 (~RD), U1.7 (VIN(-)), U1.8 (AGND), U1.10 (DGND)
unnamed: J1.1, U1.18 (DB0)
unnamed: J1.2, U1.17 (DB1)
unnamed: J1.3, U1.16 (DB2)
unnamed: J1.4, U1.15 (DB3)
unnamed: J1.5, U1.14 (DB4)
unnamed: J1.6, U1.13 (DB5)
unnamed: J1.7, U1.12 (DB6)
unnamed: J1.8, U1.11 (DB7)
unnamed: J2.1, U1.3 (~WR)
unnamed: R1.1, U1.4 (CLK_IN)
unnamed: C1.2, R1.2, U1.19 (CLK_R)
VCC: J3.1, U1.20 (VCC)

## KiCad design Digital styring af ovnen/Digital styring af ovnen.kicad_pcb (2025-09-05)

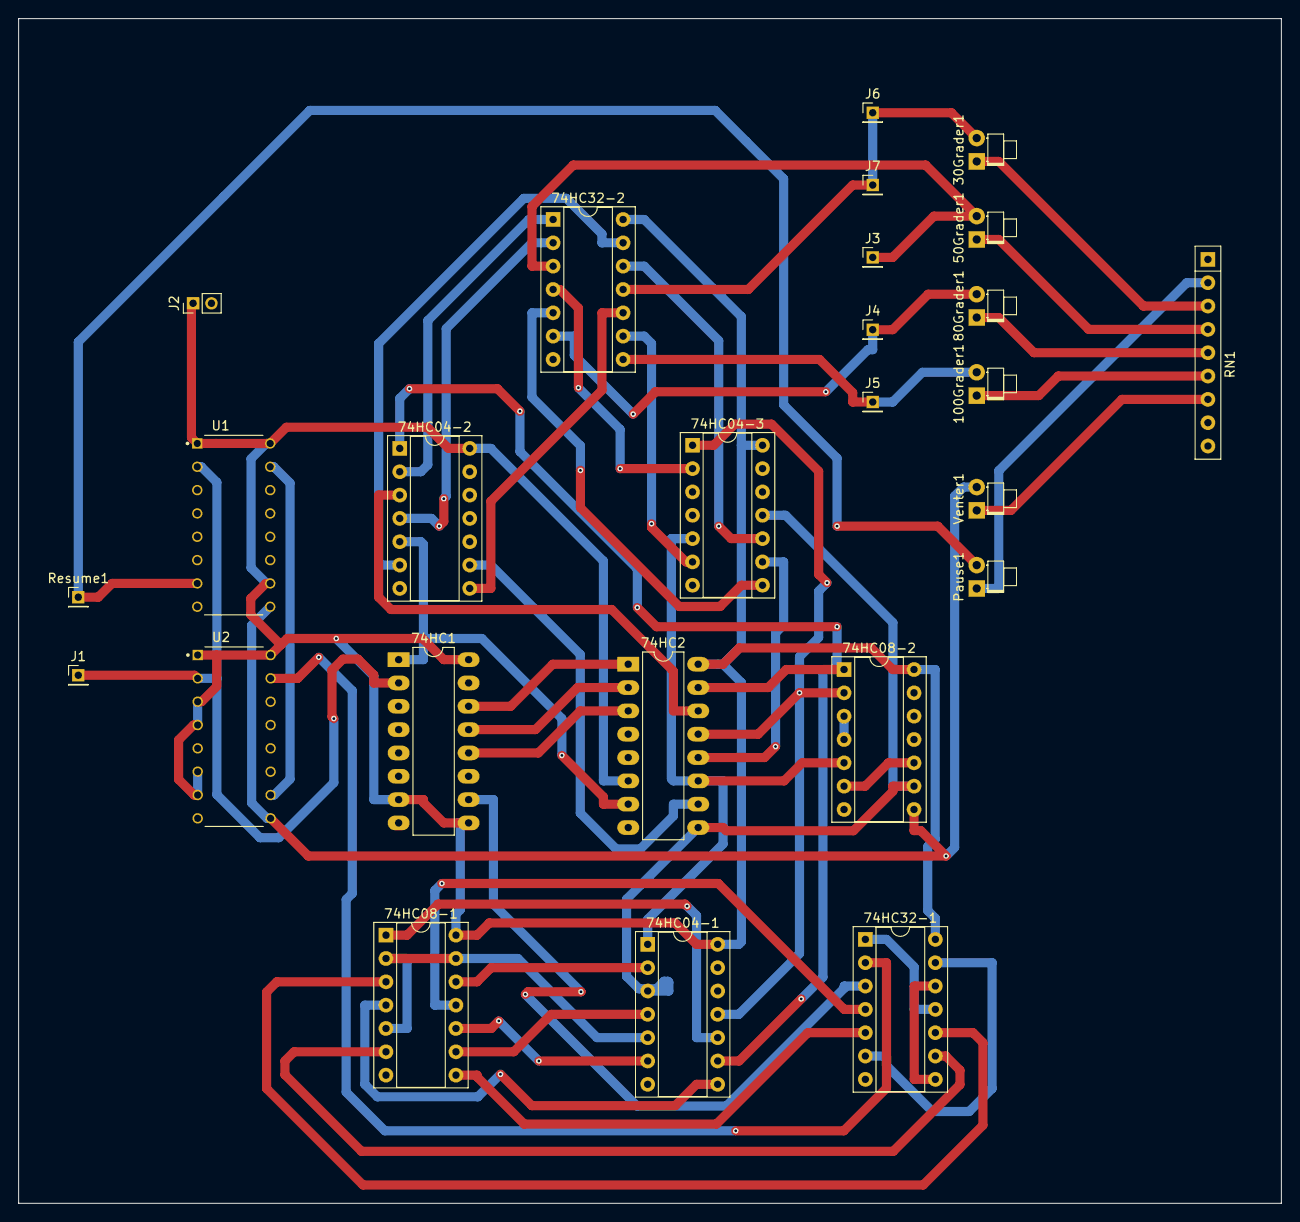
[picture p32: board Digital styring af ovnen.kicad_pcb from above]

Board: 2 copper layers, 137.5 x 129.0 mm, 26 parts (0 on the bottom side), 52 nets.

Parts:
30Grader1, 50Grader1, 80Grader1, 100Grader1: LED; LED_D1.8mm_W1.8mm_H2.4mm_Horizontal_O1.27mm_Z8.2mm
74HC1, 74HC2: DIP-16_W7.62mm_LongPads
74HC04-1, 74HC04-2, 74HC04-3, 74HC08-1, 74HC08-2, 74HC32-1, 74HC32-2: DIP-14_W7.62mm_Socket
J1: 1Hz; PinHeader_1x01_P2.00mm_Vertical
J2: Conn_01x02_Pin; PinHeader_1x02_P2.00mm_Vertical
J3: 50 Grader; PinHeader_1x01_P2.00mm_Vertical
J4: 80 Grader; PinHeader_1x01_P2.00mm_Vertical
J5: 100 grader; PinHeader_1x01_P2.00mm_Vertical
J6: Blæser; PinHeader_1x01_P2.00mm_Vertical
J7: 30 Grader; PinHeader_1x01_P2.00mm_Vertical
Pause1: LED; LED_D1.8mm_W1.8mm_H2.4mm_Horizontal_O1.27mm_Z8.2mm
RN1: R_Network08; R_Array_SIP9
Resume1: PinHeader_1x01_P2.00mm_Vertical
U1, U2: SN74HC163N; DIP794W45P254L1969H508Q16
Venter1: LED; LED_D1.8mm_W1.8mm_H2.4mm_Horizontal_O1.27mm_Z8.2mm

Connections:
+5V: 74HC1.7 (CEP), 74HC1.9 (Load), 74HC1.16 (Vcc), 74HC2.6 (E3), 74HC2.16 (Vcc), 74HC04-1.14 (Vcc), 74HC04-2.14 (Vcc), 74HC04-3.14 (Vcc), 74HC08-1.14 (Vcc), 74HC08-2.14 (Vcc), 74HC32-1.14 (Vcc), 74HC32-2.14 (Vcc), J2.1, U1.1 (~MR), U1.10 (CET), U1.16 (VCC), U2.1 (~MR), U2.3 (D0), U2.4 (D1), U2.6 (D3), U2.7 (CEP), U2.16 (VCC)
/30 C: 30Grader1.2 (A), 74HC32-2.11 (4Y), J6.1, J7.1
/50 C: 50Grader1.2 (A), 74HC32-2.3 (1Y), J3.1
/80 C: 74HC32-2.6 (2Y), 80Grader1.2 (A), J4.1
/100 C: 74HC32-2.8 (3Y), 100Grader1.2 (A), J5.1
/Clk 1Hz: 74HC1.2 (CP), J1.1, U1.2 (CLK), U2.2 (CLK)
/Resume: Pause1.2 (A), Resume1.1, U1.7 (CEP)
/komparator input: 74HC04-1.5 (3A), 74HC08-1.2 (1B), 74HC08-1.5 (2B), 74HC08-1.13 (4B)
GND: 74HC1.3 (D0), 74HC1.4 (D1), 74HC1.5 (D2), 74HC1.6 (D3), 74HC1.8 (GND), 74HC2.4 (E1), 74HC2.5 (E2), 74HC2.8 (GND), 74HC04-1.7 (GND), 74HC04-2.7 (GND), 74HC04-3.7 (GND), 74HC08-1.7 (GND), 74HC08-2.7 (GND), 74HC32-1.7 (GND), 74HC32-2.7 (GND), J2.2, RN1.1 (common), U1.3 (D0), U1.4 (D1), U1.5 (D2), U1.6 (D3), U1.8 (GND), U2.5 (D2), U2.8 (GND)
unnamed: 30Grader1.1 (K), RN1.3 (R2)
unnamed: 50Grader1.1 (K), RN1.4 (R3)
unnamed: 74HC1.10 (CET), 74HC32-1.3 (1Y)
unnamed: 74HC1.14 (Q0), 74HC2.1 (A0)
unnamed: 74HC1.13 (Q1), 74HC2.2 (A1)
unnamed: 74HC1.12 (Q2), 74HC2.3 (A3)
unnamed: 74HC2.11 (Y4), 74HC04-1.1 (1A), 74HC04-3.5 (3A), 74HC08-2.5 (2B)
unnamed: 74HC04-1.2 (1Y), 74HC08-1.12 (4A)
unnamed: 74HC2.9 (Y6), 74HC04-1.3 (2A), 74HC04-3.11 (5A), 74HC08-2.9 (3A)
unnamed: 74HC04-1.4 (2Y), 74HC08-1.9 (3A)
unnamed: 74HC04-1.6 (3Y), 74HC08-1.10 (3B)
unnamed: 74HC2.15 (Y0), 74HC04-1.9 (4A), 74HC04-2.1 (1A), 74HC08-2.1 (1A)
unnamed: 74HC04-1.8 (4Y), 74HC08-1.4 (2A)
unnamed: 74HC2.13 (Y2), 74HC04-1.11 (5A), 74HC04-3.1 (1A), 74HC08-2.2 (1B)
unnamed: 74HC04-1.10 (5Y), 74HC08-1.1 (1A)
unnamed: 74HC04-2.2 (1Y), 74HC32-2.1 (1A)
unnamed: 74HC2.14 (Y1), 74HC04-2.3 (2A)
unnamed: 74HC04-2.4 (2Y), 74HC32-2.2 (1B)
unnamed: 74HC1.1 (MR), 74HC2.7 (Y7), 74HC04-2.5 (3A)
unnamed: 74HC04-2.6 (3Y), 74HC32-2.13 (4B)
unnamed: 74HC2.10 (Y5), 74HC04-2.9 (4A)
unnamed: 74HC04-2.8 (4Y), 74HC32-2.10 (3B)
unnamed: 74HC04-3.2 (1Y), 74HC32-2.4 (2A)
unnamed: 74HC04-3.6 (3Y), 74HC32-2.9 (3A)
unnamed: 74HC2.12 (Y3), 74HC04-3.9 (4A)
unnamed: 74HC04-3.8 (4Y), 74HC32-2.5 (2B)
unnamed: 74HC04-3.10 (5Y), 74HC32-2.12 (4A)
unnamed: 74HC08-1.3 (1Y), 74HC32-1.10 (3B)
unnamed: 74HC08-1.6 (2Y), 74HC32-1.9 (3A)
unnamed: 74HC08-1.8 (3Y), 74HC32-1.5 (2B)
unnamed: 74HC08-1.11 (4Y), 74HC32-1.4 (2A)
unnamed: 74HC08-2.3 (1Y), 74HC08-2.4 (2A)
unnamed: 74HC08-2.6 (2Y), 74HC08-2.10 (3B)
unnamed: 74HC08-2.8 (3Y), U1.9 (~LOAD), U2.9 (~LOAD), Venter1.2 (A)
unnamed: 74HC32-1.1 (1A), 74HC32-1.11 (4Y)
unnamed: 74HC32-1.2 (1B), U2.15 (TC)
unnamed: 74HC32-1.6 (2Y), 74HC32-1.13 (4B)
unnamed: 74HC32-1.8 (3Y), 74HC32-1.12 (4A)
unnamed: 80Grader1.1 (K), RN1.5 (R4)
unnamed: 100Grader1.1 (K), RN1.6 (R5)
unnamed: Pause1.1 (K), RN1.2 (R1)
unnamed: RN1.7 (R6), Venter1.1 (K)
unnamed: U1.15 (TC), U2.10 (CET)

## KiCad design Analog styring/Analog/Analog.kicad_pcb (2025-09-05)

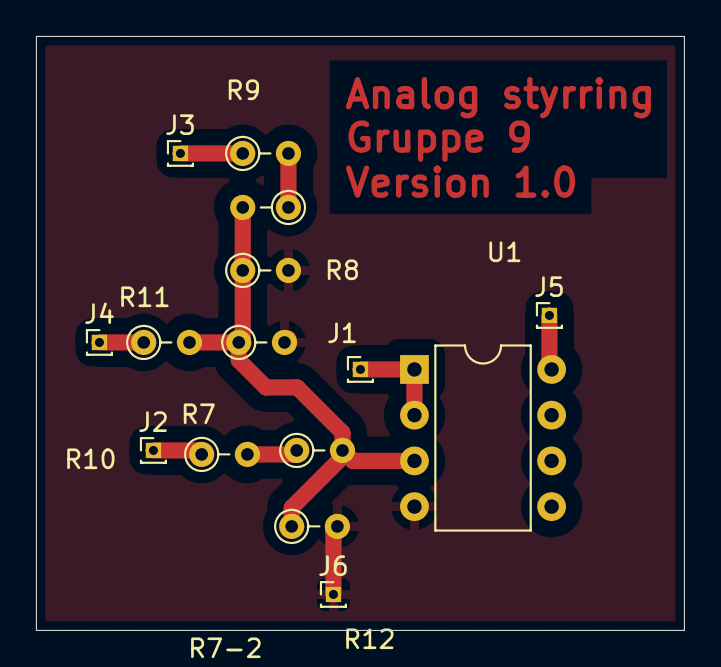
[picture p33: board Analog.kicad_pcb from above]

Board: 2 copper layers, 36.0 x 33.0 mm, 15 parts (0 on the bottom side), 9 nets.

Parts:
J1, J2, J3, J4, J5, J6: Conn_01x01_Pin; PinHeader_1x01_P1.00mm_Vertical
R7: 200R; R_Axial_DIN0204_L3.6mm_D1.6mm_P2.54mm_Vertical
R7-2: 30K9; R_Axial_DIN0204_L3.6mm_D1.6mm_P2.54mm_Vertical
R8, R10, R12: 45K; R_Axial_DIN0204_L3.6mm_D1.6mm_P2.54mm_Vertical
R9: 604R; R_Axial_DIN0204_L3.6mm_D1.6mm_P2.54mm_Vertical
R9-2: 46K4; R_Axial_DIN0204_L3.6mm_D1.6mm_P2.54mm_Vertical
R11: 75K; R_Axial_DIN0204_L3.6mm_D1.6mm_P2.54mm_Vertical
U1: LF398_DIP8; DIP-8_W7.62mm

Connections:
Earth: J6.1, R8.2, R10.2, R12.2, U1.4 (V^{-})
unnamed: J1.1, U1.1 (V^{+}), U1.2 (Adj)
unnamed: J2.1, R7.1
unnamed: J3.1, R9.1
unnamed: J4.1, R11.1
unnamed: J5.1, U1.8 (Hold)
unnamed: R7.2, R7-2.1
unnamed: R9.2, R9-2.1
unnamed: R7-2.2, R8.1, R9-2.2, R10.1, R11.2, R12.1, U1.3 (I)
